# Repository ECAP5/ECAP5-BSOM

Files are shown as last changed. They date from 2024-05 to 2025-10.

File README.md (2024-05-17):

<br />
<div align="center">
    

  <h3 align="center">ECAP5-BSOM</h3>

  <p align="center">
    System-On-Module board for ECAP5
    <br />
    <a href="https://ecap5.github.io/ECAP5-BSOM/"><strong>Explore the docs »</strong></a>
    <br />
  </p>
</div>

## Licenses

- Software and configuration files are distributed under the GPL-3.0 license.
- Hardware is distributed under the CERN-OHL-S license.

See licence files for more information.

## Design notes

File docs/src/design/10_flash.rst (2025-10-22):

(F7) FLASH
==========

Functional description
----------------------

Design constraints
------------------

.. requirement:: D_FLASH_01
   :rationale: Only 32MBits are required to store the FPGA bitstream but the extra storage can be used by the user more easily than the eMMC. This reference supports optional programmable QSPI interface.

   The board shall include a 128Mbits NOR flash memory with reference W25Q128JVPIM to store the FPGA bitstream used in Quad-SPI configuration.

The following requirements are extracted from the datasheet of W25Q128JVPIM [:ref:^DS1 <reftable>^].

.. requirement:: D_FLASH_01
   :rationale: This corresponds to a 10% precision arround 3.3V.
   :derivedfrom: U_FLASH_01

   The VCC supply voltage shall be within 3.0V and 3.6V with a current capacity of 25mA.

.. requirement:: D_FLASH_02
   :derivedfrom: U_FLASH_01

   The CS input shall track the VCC supply levet at power-up and power-down using a pull-up resistor.

.. requirement:: D_FLASH_03
   :derivedfrom: U_FLASH_01

   The time between VCC reaching 3.0V to the CS pin being pulled low shall be at least 20us.

This requirement implies that the FPGA must not start its configuration before 20us after VCC reaches 3.0V.

.. requirement:: D_FLASH_04
   :derivedfrom: U_FLASH_01

   The time between VCC reaching 2.0V and the first write instruction shall be at least 5ms.

This requirement is only provided as information as write operations are only performed by the board designer while the board is already up and running.

Circuit diagram
---------------

Design calculations
-------------------

Simulation results
------------------

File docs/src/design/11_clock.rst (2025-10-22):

(F8) CLOCK
==========

Functional description
----------------------

Design constraints
------------------

.. requirement:: D_OSC_01
   :rationale: 40MHz LVCMOS, Enable/Disable on pin 1, 3.2x2.5mm package, 3.3VDC±5% supply, ±50ppm precision, -40 to +85°C temperature range.

   A 40 MHz reference oscillator shall be connected to one of the FPGA's global clock inputs, with reference XLH335040.000000I.

The following requirements are extracted from the datasheet of XLH736030.000000I [:ref:^DS6 <reftable>^].

Supply Voltage
^^^^^^^^^^^^^^

.. requirement:: D_OSC_01
   :derivedfrom: U_OSC_01

   The VDD supply voltage shall be within 3.135V and 3.465V with a current capacity of 35mA.

.. requirement:: D_OSC_02
   :derivedfrom: U_OSC_01

   A 0.01uF bypass capacitor shall be placed between VDD and GND.

Circuit diagram
---------------

Design calculations
-------------------

Simulation results
------------------

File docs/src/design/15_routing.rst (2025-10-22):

Routing
=======

Stackup
-------

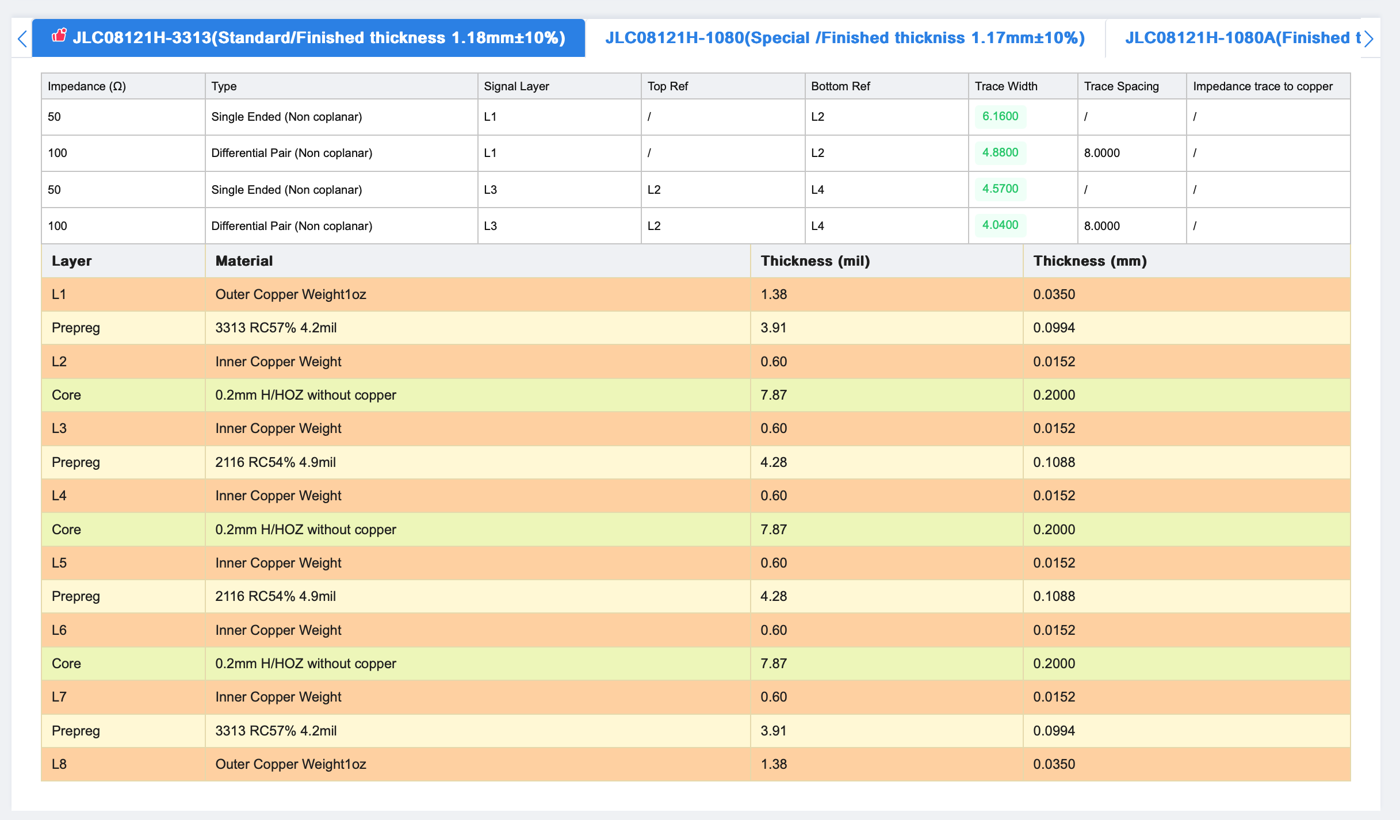
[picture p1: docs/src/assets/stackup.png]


The stackup used is JLCPCB's JLC08121H-3313 1.2mm pcb stackup.

.. flat-table:: Layer allocation
   :header-rows: 1
   :width: 100%

   * - Layer
     - Allocation

   * - Top layer L1
     - High-Speed signals

   * - Inner Layer L2
     - GND

   * - Inner Layer L3
     - High-Speed signals

   * - Inner Layer L4
     - Power

   * - Inner Layer L5
     - Power

   * - Bottom layer L6
     - High-Speed signals

   * - Bottom layer L7
     - GND

   * - Bottom layer L8
     - High-Speed signals

Trace impedance
---------------

.. flat-table:: Net classes
   :header-rows: 1
   :width: 100%

   * - Impedance
     - Layer
     - Trace width
     - Differencial-pair spacing

   * - Single-ended 50ohms
     - L1/L6
     - 6.16mil (0,156464mm)
     - N/A

   * - Differencial 100ohm
     - L1/L6
     - 4.88mil (0,123952mm)
     - 8.0mil (0,2032mm)

   * - Single-ended 50ohms
     - L4
     - 4.57mil (0,116mm)
     - N/A

   * - Differencial 100ohm
     - L4
     - 4.04mil (0,102616mm)
     - 8.0mil (0,2032mm)

Signal propagation
------------------

The propagation speed is computed with the following formulas :

.. math::

   v_{\text{microstrip}} = \frac{c_{\text{vacuum}}}{\sqrt{Dk_{eff}}}

.. math::

   v_{\text{stripline}} = \frac{c_{\text{vacuum}}}{\sqrt{Dk}}

where Dkeff for a 0.15mm stripline with a Dk of 4.6 is 2.87749 and the speed of light in vacuum is 299792458m/s.

.. flat-table:: Trace propagation on stackup layers
   :header-rows: 1
   :width: 100%
   
   * - Layer
     - Type
     - Propagation

   * - L1/L6
     - Single-Ended
     - ~5ps/mm

   * - L4
     - Single-Ended
     - ~7ps/mm

   * - L1/L6
     - Differencial
     - 

   * - L4
     - Differencial
     -

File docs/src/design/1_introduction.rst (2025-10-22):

Introduction
============

Purpose
-------

This documents aims at defining the functional requirements for ECAP5-BSOM as well as documenting the design process.

Product Scope
-------------

ECAP5-BSOM is a System-On-Module board which shall provide ECAP5 with a general-purpose FPGA platform including integrated memory, flash storage and high-speed interfaces.

Intended Use
-------------------------

ECAP5-BSOM is targetted at ECAP5 

Conventions
-----------

Requirement format
^^^^^^^^^^^^^^^^^^

This document details requirements with the following format :

.. list-table:: Sample requirement
  :width: 100%
  :widths: 10 90

  * - **ID**
    - Requirement_ID

  * - **Description**
    - Requirement description

  * - **Rationale**
    - Requirement rationale

  * - **DerivedFrom**
    - Other_Requirement_ID

with requirement IDs having the following format :

  * ``U_*``: User requirements
  * ``D_*``: Design requirements

Definitions and Abbreviations
-----------------------------

.. todo:: Update the ref table

.. _reftable:

References
----------

.. list-table::
  :header-rows: 1
  :widths: 10 20 15 55
  :width: 100%
  
  * - Reference
    - Date
    - Version
    - Title

  * - DS1
    - March 27, 2018
    - Revision F
    - W25Q128JV 3V 128M-Bit Serial Flash Memory with Dual/Quad SPI

  * - DS2
    - October 1, 2019
    - Revision 2.0
    - THGBMJG6C1LBAIL e-MMC Module

  * - DS3
    - July 20, 2022
    - Revision H2
    - IS61WV25616BLL 256K x 16 High Speed Asynchronous CMOS Static RAM 

  * - DS4
    - September 16, 2020
    - Revision C4
    - IS42S16160J 16Meg x16 256Mb Synchronous DRAM

  * - DS5
    - December 11, 2017
    - Revision B
    - IS43DR16320E 32Mx16 DDR2 DRAM

  * - DS6
    - September 21, 2023
    - N/A
    - Plastic Package Ultra Miniature Pure Silicon Clock Oscillators

  * - AN1
    - May, 2023
    - 1.4
    - FPGA-TN-02210 Power Consumption and Management for ECP5 and ECP5-5G Devices

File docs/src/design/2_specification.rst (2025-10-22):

Specification
=============

.. requirement:: U_FPGA_01
   :rationale: 85k LUTs with 365 I/Os. The speed grade of the part is not specified.

   The board shall include a Lattice ECP5 FPGA with reference LFE5U-85F-*BG756C.

.. requirement:: U_CLOCK_01

   The board shall include a 40MHz clock generator which shall be connected to one of the FPGA's global input clock pins.

.. requirement:: U_MEMORY_01

   The board shall include a 16-bit SRAM memory IC.

.. requirement:: U_MEMORY_02

   The board shall include two 16-bit SDRAM memory ICs to form a 32-bit data bus (shared address bus, separate data/ctrl buses).

.. requirement:: U_MEMORY_03

   The board shall include a 8-bit DDR2 memory IC.

.. note:: Multiple different memory technologies are integrated into the board to allow experimenting with memory controller development.

.. requirement:: U_STORAGE_01
   :rationale: 32Mb of storage is enough to store the FPGA bitstream but a bigger IC can be used to store user data.

   The board shall include a Quad-SPI Flash memory IC with at least 32Mb of storage which shall be connected to the FPGA sysConfig pins.

.. requirement:: U_STORAGE_02

   The board shall include an eMMC flash memory IC with HS200 support.

.. requirement:: U_CONNECTOR_01

   The board shall expose its various interfaces using a DDR4 SO-DIMM 260pin edge-card connector with the following pinout



.. list-table:: SO-DIMM IO Connector Signal Description
   :header-rows: 1
   :width: 100%

   * - Name
     - Type
     - Description

   * - JTAG_TCK
     - I
     - JTAG clock input
   * - JTAG_TDI
     - I
     - JTAG data input
   * - JTAG_TDO
     - O
     - JTAG data output
   * - JTAG_TMS
     - I
     - JTAG test mode select input
   * - SE[0-67]
     - I/O
     - Single-Ended general purpose 3v3 input/output
   * - RTD[0-64][P/N]
     - I
     - General purpose input/output LVDS2V5
   * - RESET_I
     - I
     - Reset input
   * - VIN9_20
     - 
     - Main power input 9~20V
   * - unused
     - 
     - 
   * - GND
     - 
     - 

.. note:: Unused pins are left unconnected but reserved on the connector for future use.

.. requirement:: U_POWER_01

   The board shall be powered by the 9-15V power inputs from the IO connector.

.. requirement:: U_MECHANICAL_01
   :rationale: The board can be as tall as needed.

   The board shall match the DDR4 SO-DIMM edge-card horizontal dimensions and features.

.. requirement:: U_MECHANICAL_02

   The board shall include mounting holes around the FPGA to mount a heatsink.

.. requirement:: U_LED_01

   The board shall include a status LED which shall indicicate the status of the FPGA.

.. requirement:: U_LED_02

   The board shall include a user LED which shall be driven by the FPGA.

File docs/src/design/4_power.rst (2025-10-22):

(F1) Power
==========

Functional description
----------------------

The power sub-circuit is in charge of converting the supply voltage from the IO connector to the following supply voltages required for the board's operation :

.. flat-table:: Supply Voltage Requirements
   :header-rows: 1
   :width: 100%

   * - Voltage
     - Current capacity requirement

   * - 1.1V ±5%
     - 3.5A
   * - 2.5V ±5%
     - 500mA
   * - 3.3V ±5%
     - 1A
   * - 1.8V ±5%
     - 500mA

The sub-circuit enables the voltage regulators in the following sequence, with a 10ms delay:



|

.. note:: The 3.3V voltage regulator is enabled by default so it can power the power sequencing IC.

The power sub-circuit also includes power monitoring ICs (IN219) to measure both voltage and current over an I2C bus. The following I2C addresses are used :

.. flat-table:: Supply monitoring I2C addresses
   :header-rows: 1
   :width: 100%

   * - Supply
     - I2C address

   * - 1.1V
     - 0x85
   * - 1.8V
     - 0x84
   * - 2.5V
     - 0x81
   * - 3.3V
     - 0x80

Power monitors are powered by a separate 5V LDO.

Design constraints
------------------

N/A

Circuit diagram
---------------

1.1V regulator
``````````````

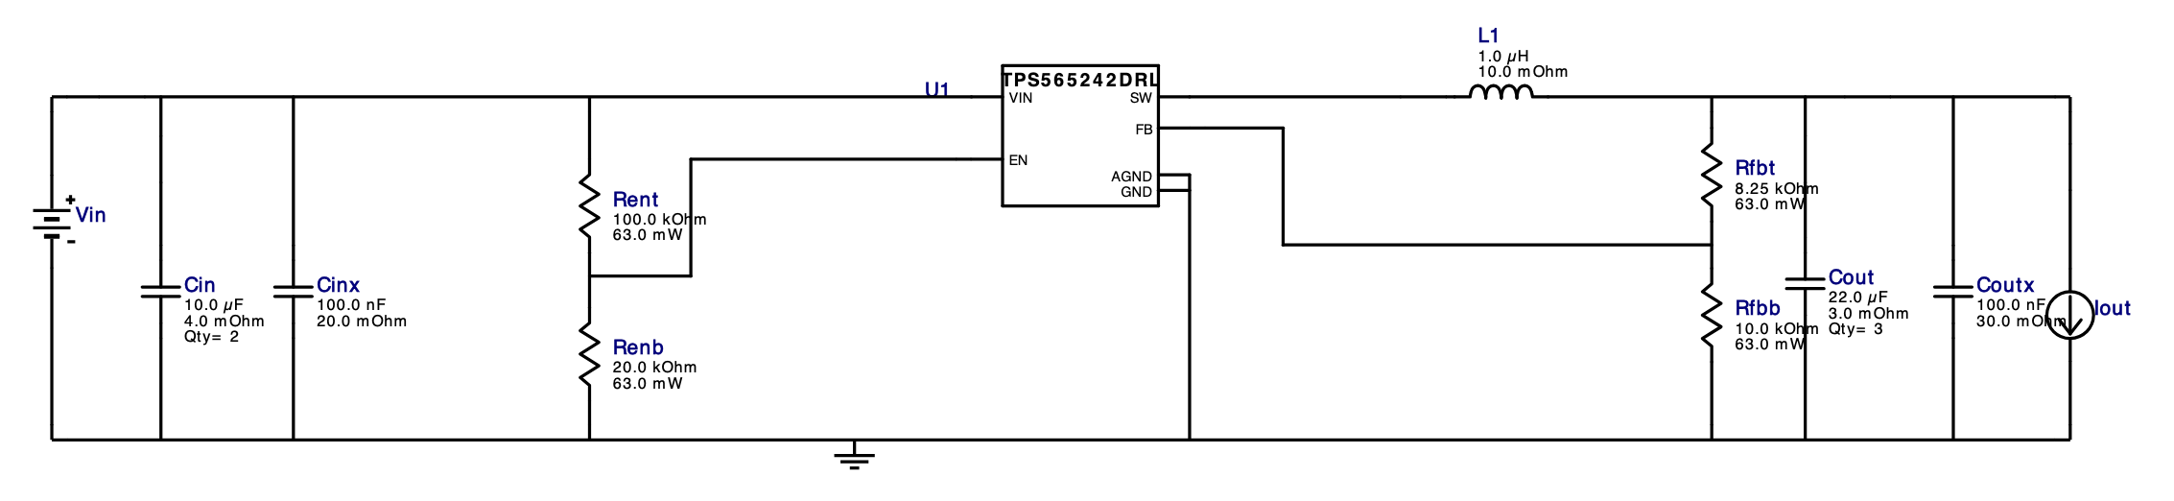
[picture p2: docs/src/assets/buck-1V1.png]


Refer to the following document for full details : `buck-1.1-report.pdf <../_static/buck-1.1-report.pdf>`_.

1.8V regulator
``````````````

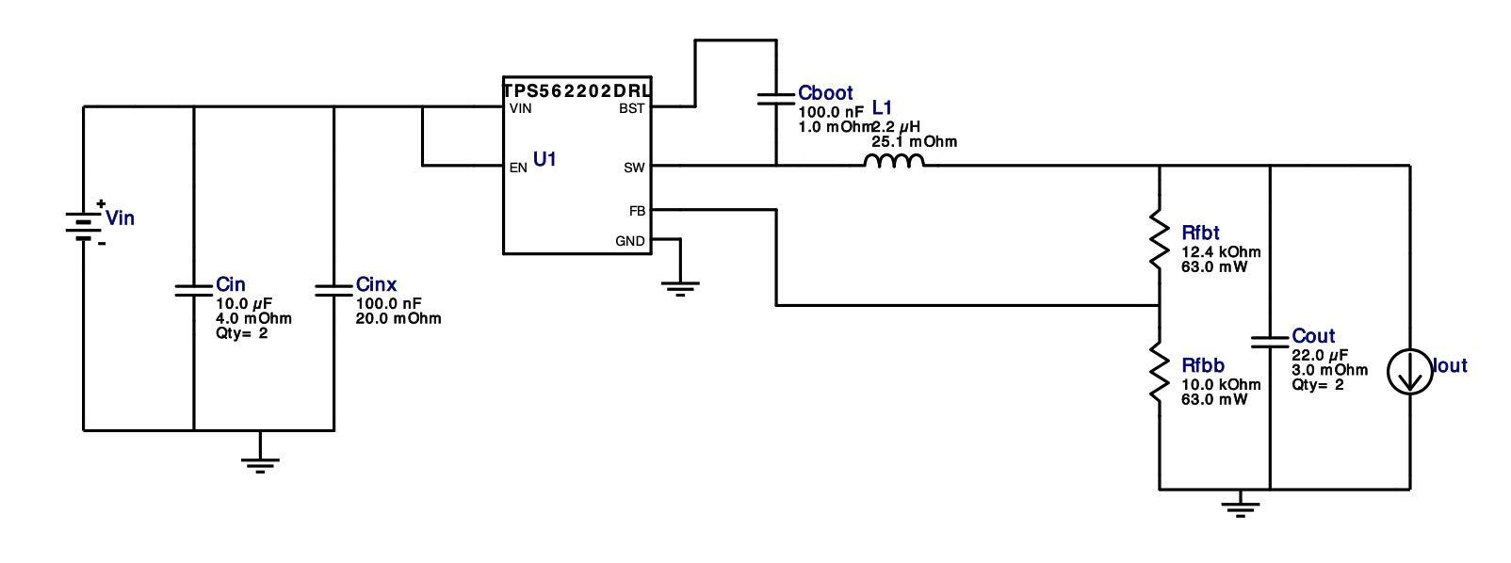
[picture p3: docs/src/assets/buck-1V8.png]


Refer to the following document for full details : `buck-1.8-report.pdf <../_static/buck-1.8-report.pdf>`_.

2.5V regulator
``````````````

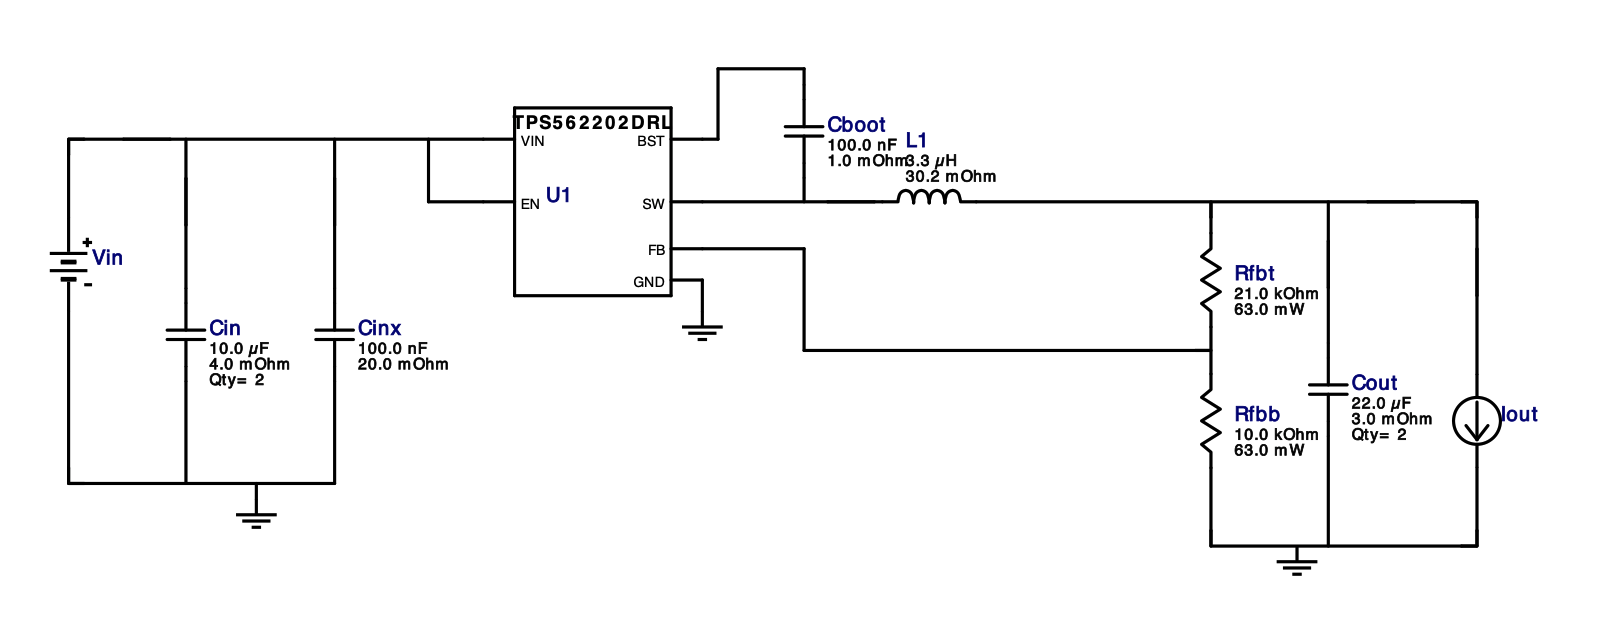
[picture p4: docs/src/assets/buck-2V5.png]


Refer to the following document for full details : `buck-2.5-report.pdf <../_static/buck-2.5-report.pdf>`_.

3.3V regulator
``````````````

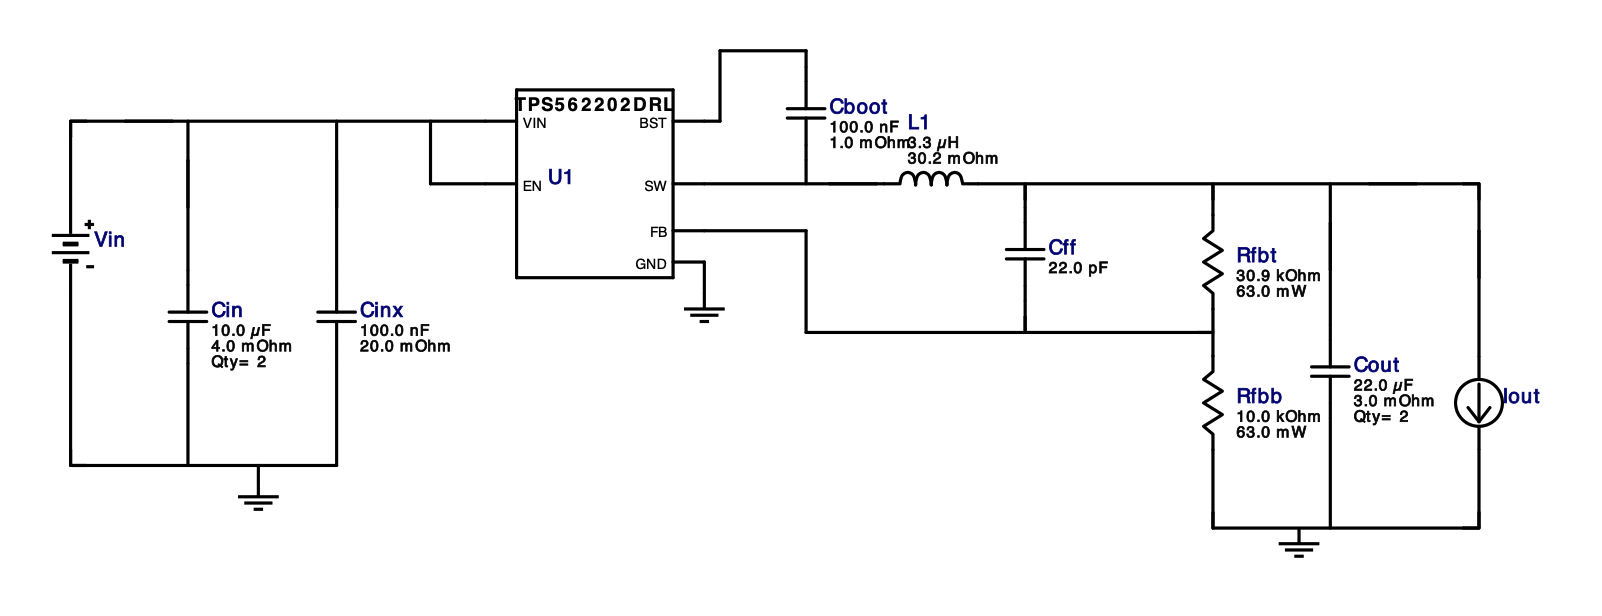
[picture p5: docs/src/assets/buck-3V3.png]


Refer to the following document for full details : `buck-3.3-report.pdf <../_static/buck-3.3-report.pdf>`_.

Power sequencing
````````````````



.. flat-table:: Power sequencer IC
   :stub-columns: 1
   :width: 100%

   * - IC
     - LM3880
   * - Sequence Number
     - 1 (1-2-3 / 3-2-1)
   * - Timing Designator
     - AA (10ms)
   * - Ordering reference
     - LM3880MF*-1AA

Design calculations
-------------------

Supply requirements
```````````````````

In order to perform a rough FPGA power estimation, the following assumptions were taken :

- LFE5U-85F-8BG756C reference
- 200MHz internal frequency
- 25% Activity Factor (as stated in :ref:`AN1 <reftable>`)
- 70% logic utilization
- 100% BRAM utilization
- 64 LVDS input differential pairs
- eMMC IOs
- SRAM Address/Data IOs
- SDRAM Address/DQ IOs
- DDR2 Address/DQ IOs

.. note:: I/O utilization isn't precisely modelled as the IO power consumption is low. Margins will be taken to prevent any supply issues.

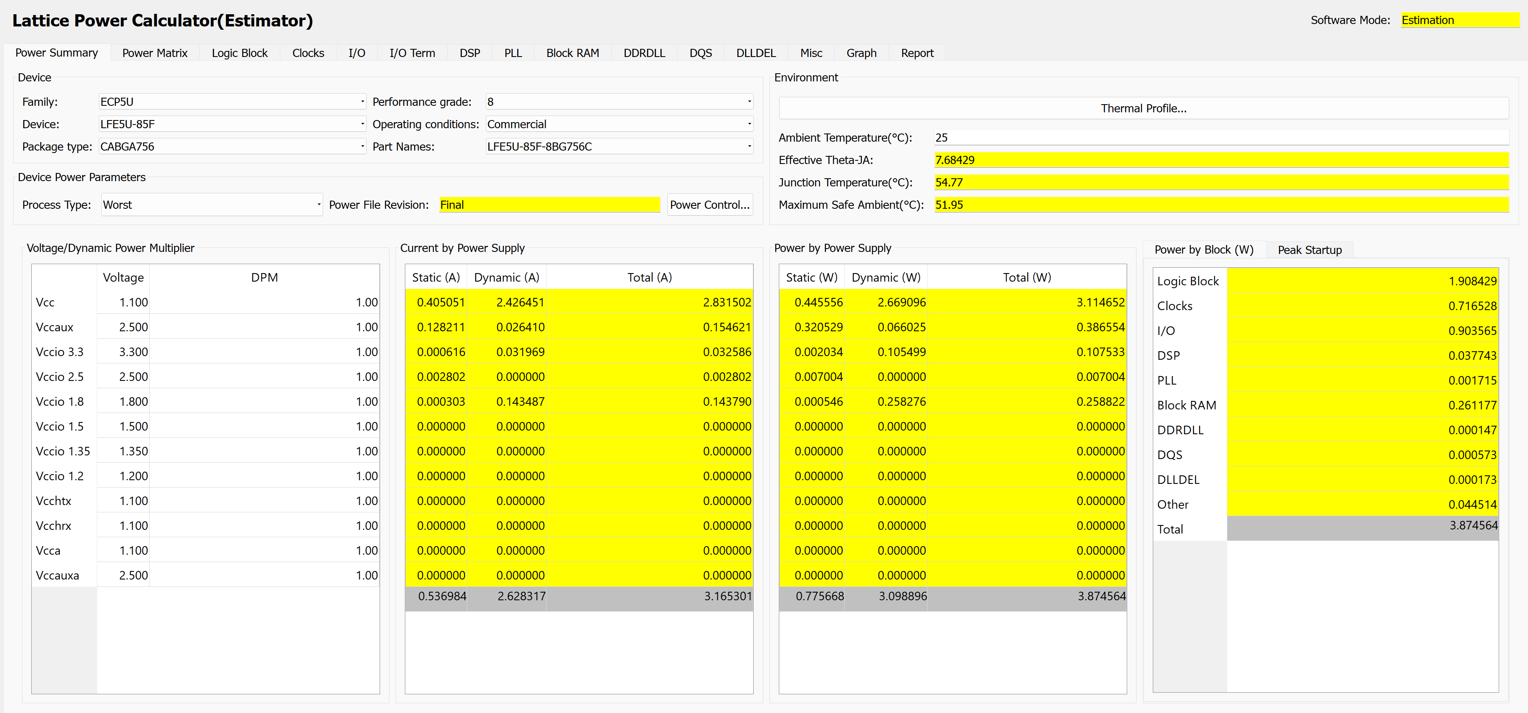
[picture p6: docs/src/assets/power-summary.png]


|

The following table outlines the voltage requirements of the specified components :

.. flat-table:: Component Supply Voltage Requirements
   :header-rows: 1
   :width: 100%

   * - Component
     - Name
     - Voltage
     - Max Current
     - Description
   
   * - :rspan:`3` LFE5U-85F-*BG756C
     - VCC
     - 1.1V ±5%
     - 3A
     - Core Supply Voltage
   * - VCCAUX
     - 2.5V ±5%
     - 200mA
     - Auxilary Supply Voltage
   * - VCCIO[*]
     - 
     - 
     - 
   * - VCCIO8
     - 3.3V ±10%
     - 100mA
     - sysIO bank Supply Voltage
   * - IS61W25616BLL
     - VDD
     - 3.3V ±5%
     - 50mA
     - Supply Voltage
   * - :rspan:`1` IS42S16160J x2
     - VDD
     - 3.3V ±10%
     - 140mA x2
     - Supply Voltage
   * - VDDQ
     - 3.3V ±10%
     - *included in VDD*
     - I/O Supply Voltage
   * - :rspan:`2` IS43DR86400E
     - VDD
     - 1.8V ±5%
     - 185mA
     - Supply Voltage
   * - VDDQ
     - 1.8V ±5%
     - *included in VDD*
     - I/O Supply Voltage
   * - VDDL
     - 1.8V ±5%
     - *included in VDD*
     - DLL Supply Voltage
   * - W25Q158JVPIM
     - VCC
     - 3.3V ±10%
     - 25mA
     - Supply Voltage
   * - :rspan:`1` ASFC4G31M-51BIN
     - VCCQ
     - 1.8V ±8%
     - 120mA
     - Host Interface Supply Voltage
   * - VCC
     - 3.3V ±10%
     - 120mA
     - Memory Supply Voltage

Power Sequencing
````````````````

.. flat-table:: Power-up timings
   :header-rows: 1
   :stub-columns: 2
   :width: 100%

   * - IC
     - Voltage
     - Max ramp rate
     - Max start time
   * - ST1S41PHR
     - 1.1V
     - 1.1mV/us
     - 1ms
   * - L6981NDR
     - 1.8V
     - 1.8mV/us
     - 1.6ms
   * - L6981NDR
     - 2.5V
     - 2.5mV/us
     - 1.6ms
   * - L6981NDR
     - 3.3V
     - 3.3mV/us
     - 1.6ms

The following formula is used to compute the value of :math:`C_{\text{en}}` which applies a delay to the start of the sequence:

.. math::

   t_{\text{enable_delay}} = \frac{1.25V * C_{\text{en}}}{7 \mu A}

:math:`t_{\text{enable_delay}}` must greater than the start time of the 3.3V regulation (ie. 1.6ms), therefore :

.. math::

  C_{\text{en}} = 56nF \implies t_{\text{enable_delay}} = 10ms

Power monitoring
````````````````

In order to minimize the voltage drop induced by the shunt resistor, the following values have been chosen, considering a full range shunt resistor voltage of 40mV :

.. flat-table:: Power monitoring shunt resistor
   :header-rows: 1
   :width: 100%

   * - Supply
     - Max current
     - Shunt resistor
     - Max voltage drop

   * - 1.1V
     - 4A
     - 2.2mOhms
     - 8.8mV
   * - 1.8V
     - 1A
     - 22mOhms
     - 22mV
   * - 2.5V
     - 1A
     - 39mOhms
     - 39mV
   * - 3.3V
     - 1A
     - 39mOhms
     - 39mV

.. note:: The smaller shunt resistors on 1.1V and 1.8V supplies will result in a lower power measurement precision but allows for a greater voltage margin.

Simulation results
------------------

1.1V Core
`````````

Refer to the following document for full details : `buck-1.1-report.pdf <../_static/buck-1.1-report.pdf>`_.

1.8V
````

Refer to the following document for full details : `buck-1.8-report.pdf <../_static/buck-1.8-report.pdf>`_.

2.5V
````

Refer to the following document for full details : `buck-2.5-report.pdf <../_static/buck-2.5-report.pdf>`_.

3.3V
````

Refer to the following document for full details : `buck-3.3-report.pdf <../_static/buck-3.3-report.pdf>`_.

Power sequencing
````````````````

N/A

Power integrity
---------------

A power integrity simulation was performed on the 1.1V rail as it is the most constrained. The voltage drop observed at 4A was 10mV which is within the range of the requirements.

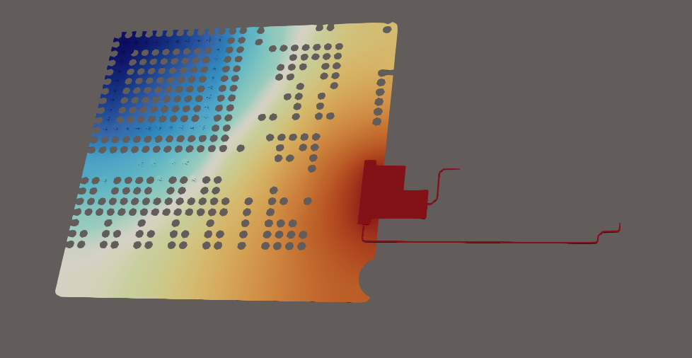
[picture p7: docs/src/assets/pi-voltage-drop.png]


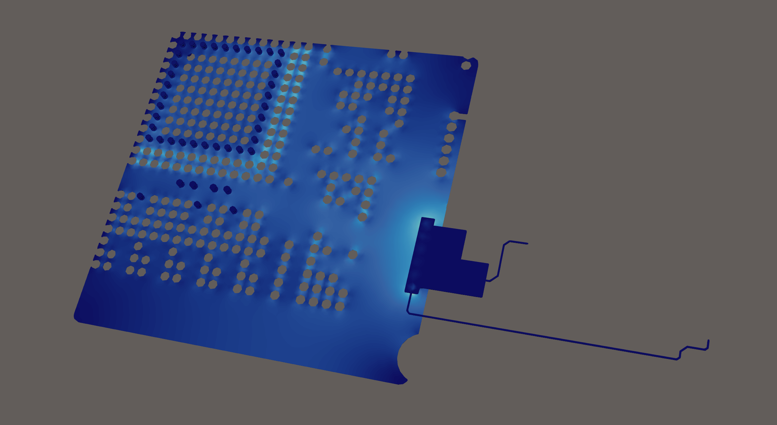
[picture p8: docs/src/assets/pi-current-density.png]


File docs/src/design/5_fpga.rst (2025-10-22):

(F2) FPGA
=========

Design constraints
------------------

Operating Conditions
^^^^^^^^^^^^^^^^^^^^

.. requirement:: D_FPGA_01
   :derivedfrom: U_FPGA_01

   A power estimation for the FPGA supply voltages shall be performed.

.. requirement:: D_FPGA_02
   :rationale: This corresponds to a 5% precision around 1.1V.
   :derivedfrom: U_FPGA_01

   The VCC supply voltage shall be within 1.045V and 1.155V.

.. requirement:: D_FPGA_03
   :rationale: This corresponds to a 5% precision around 2.5V.
   :derivedfrom: U_FPGA_01

   The VCCAUX supply voltage shall be within 2.375V and 2.625V.

.. requirement:: D_FPGA_04
   :derivedfrom: U_FPGA_01

   The VCCAUX supply voltage ramp shall not exceed 30mV/us during power-up.

.. requirement:: D_FPGA_05
   :derivedfrom: U_FPGA_01

   VCCIO[0:8] supply voltages shall be between 1.14V and 3.465V.

.. note:: Specific VCCIO[0:8] supply voltages are defined in the design section based on the FPGA pinout.

.. requirement:: D_FPGA_10
   :derivedfrom: U_FPGA_01

   Power supply ramp rate for all supplies shall not exceed 10V/ms.

.. requirement:: D_FPGA_11
   :derivedfrom: U_FPGA_01

   The following power-up sequence of supply voltages shall be implemented : VCCIO*, VCCAUX, VCC.

.. note:: The current requirement for the FPGA supply voltages is not defined in the FPGA datasheet. A power estimation is performed in the design section to provide upper current bounds.

.. requirement:: D_FPGA_12
   :derivedfrom: U_FPGA_01

   The FPGA junction temperature shall not exceed 85°C.

Configuration
^^^^^^^^^^^^^

As the FPGA sysCONFIG configuration is MSPI, only requirements targetting this configuration method are outlined.

.. requirement:: D_FPGA_13
   :derivedfrom: U_FPGA_01

   4.7kohms pull-up resistors shall be placed between the following signals and VCCIO8: TDI, TMS, TDO.

.. requirement:: D_FPGA_14
   :derivedfrom: U_FPGA_01

   A 4.7kohms pull-down resistor shall be placed between TCK and GND.

.. requirement:: D_FPGA_15
   :derivedfrom: U_FPGA_01

   4.7kohms pull-up resistors shall be placed between the following signals and VCCIO8: PROGRAMN and INITN.

.. requirement:: D_FPGA_16
   :derivedfrom: U_FPGA_01

   A 10kohms pull-up resistor shall be placed between CSSPIN and VCCIO8.

.. requirement:: D_FPGA_17
   :derivedfrom: U_FPGA_01

   A 1kohms pull-up resistor shall be placed between MCLK and VCCIO8.

.. requirement:: D_FPGA_18
   :derivedfrom: U_FPGA_01

   10kohms pull-up resistors shall be placed between CFG[2:0] and VCCIO8 when the configuration bit shall be 1. CFG[2:0] shall be directly connected to GND otherwise.

Configuration
-------------

CFGMDN[2:0]
^^^^^^^^^^^

.. requirement:: D_CONF_01
   :rationale: The sysCONFIG pins are configured as Master SPI.

   The CFGMDN[2:0] pins shall be configured as 010 using 4.7k pull-up or pull-down resistors.

IO[3:0]
^^^^^^^

.. requirement:: D_CONF_02

   10k pull-up resistors shall be used on sysCONFIG IO[3:0] pins.
   
.. requirement:: D_CONF_03

   A 1k pull-up resistor shall be used on sysCONFIG CLK pin.

PROGRAMN
^^^^^^^^

.. requirement:: D_CONF_04

   A 100nF capacitor shall be placed between PROGRAMN and GND.

INITN and DONE
^^^^^^^^^^^^^^

INITN is open-drain.

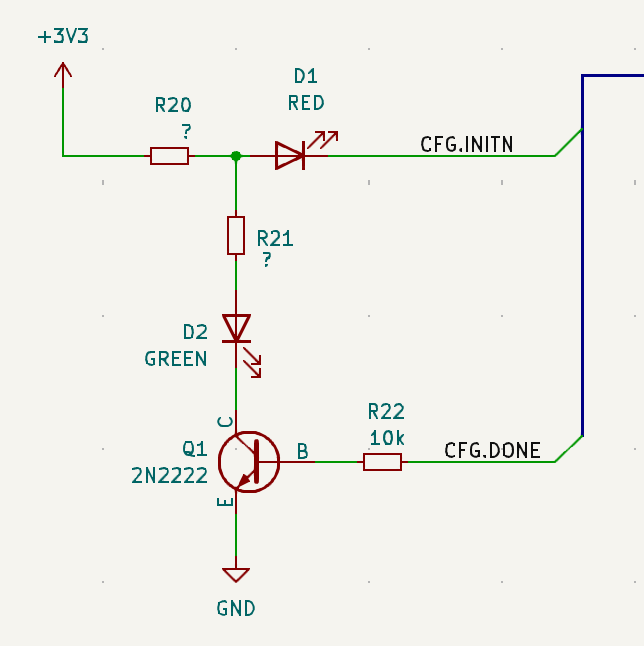
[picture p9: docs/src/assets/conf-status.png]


FPGA Pinout
-----------

The following table outlines the FPGA interface signals and their pinout constraints.

.. note:: The I/O column is from the FPGA's perspective to ease the creation of design constraints files.

.. csv-table:: Oscillator interface signals
   :header-rows: 1
   :width: 100%
   :file: ../assets/osc-pinout.csv
   :delim: ;

.. csv-table:: Flash interface signals
   :header-rows: 1
   :width: 100%
   :file: ../assets/flash-pinout.csv
   :delim: ;

.. csv-table:: eMMC interface signals
   :header-rows: 1
   :width: 100%
   :file: ../assets/emmc-pinout.csv
   :delim: ;

.. csv-table:: SRAM interface signals
   :header-rows: 1
   :width: 100%
   :file: ../assets/sram-pinout.csv
   :delim: ;

.. csv-table:: SDRAM interface signals
   :header-rows: 1
   :width: 100%
   :file: ../assets/sdram-pinout.csv
   :delim: ;

.. csv-table:: DDR2 interface signals
   :header-rows: 1
   :width: 100%
   :file: ../assets/ddr2-pinout.csv
   :delim: ;

.. csv-table:: IO connector interface signals
   :header-rows: 1
   :width: 100%
   :file: ../assets/io-pinout.csv
   :delim: ;

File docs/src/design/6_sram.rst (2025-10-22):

(F3) SRAM
=========

Functional description
----------------------

The SRAM sub-circuit is in charge of providing the user with 4MiB of Asynchronous SRAM.

Design constraints
------------------

.. requirement:: D_MEMORY_01

   The board shall include a 256k x 16bits Asynchronous SRAM with reference IS61WV25616BLL up to -8 speed grade.

The following requirements are extracted from the datasheet of IS61WV25616BLL [:ref:^DS3 <reftable>^].

.. requirement:: D_SRAM_01
   :rationale: This corresponds to an 5% precision arround 3.3V.
   :derivedfrom: U_MEMORY_01

   The VDD supply voltage shall be within 3.135V and 3.465V with a current capacity of 50mA.

.. requirement:: D_SRAM_02
   :derivedfrom: U_MEMORY_01

   The following pins shall not exceed VDD+0.3V : Address, Data and Control pins.

.. requirement:: D_SRAM_03
   :derivedfrom: U_MEMORY_01

   The following pins shall not be lower than -0.3V : Address, Data and Control pins.

Circuit diagram
---------------

Design calculations
-------------------

Simulation results
------------------

Pre-layout
``````````

The goal of the pre-layout simulation is to adjust the high-speed bus termination.

Transient behavior
^^^^^^^^^^^^^^^^^^

.. note:: No signal-integrity simulations are performed for revision 1.0.0

Eye Diagram
^^^^^^^^^^^

.. note:: No signal-integrity simulations are performed for revision 1.0.0

Post-layout
```````````

The goal of the post-layout simulation is to simulate the high-speed bus taking into account the routed trace geometry.

Transient behavior
^^^^^^^^^^^^^^^^^^

.. note:: No signal-integrity simulations are performed for revision 1.0.0

Eye Diagram
^^^^^^^^^^^

.. note:: No signal-integrity simulations are performed for revision 1.0.0

Crosstalk
^^^^^^^^^

.. note:: No signal-integrity simulations are performed for revision 1.0.0

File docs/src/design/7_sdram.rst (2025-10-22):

(F4) SDRAM
==========

Functional description
----------------------

Design constraints
------------------

.. requirement:: D_MEMORY_02

   The board shall include two 16M x 16bits 256Mb Synchronous DRAM with reference IS42S16160J up to -6 speed grade.

The following requirements are extracted from the datasheet of IS42S16160J [:ref:^DS4 <reftable>^].

.. requirement:: D_SDRAM_01
   :rationale: This corresponds to an 10% precision arround 3.3V.
   :derivedfrom: U_MEMORY_02

   The VDD and VCCQ supply voltage shall be within 3.0V and 3.6V with a current capacity of 140mA x2.

.. requirement:: D_SDRAM_02
   :derivedfrom: U_MEMORY_02

   The following pins shall not exceed VDD+0.3V : Address, Data and Control pins.

.. requirement:: D_SDRAM_03
   :derivedfrom: U_MEMORY_02

   The following pins shall not be lower than -0.3V : Address, Data and Control pins.

Circuit diagram
---------------

Design calculations
-------------------

Simulation results
------------------

Pre-layout
``````````

The goal of the pre-layout simulation is to adjust the high-speed bus termination.

The address and command trace stubs associated to the fly-by routing topology shall be smaller than 0.3/0.1Gbps = 3inch so no terminating resistors are needed.

Transient behavior
^^^^^^^^^^^^^^^^^^

.. note:: No signal-integrity simulations are performed for revision 1.0.0

Eye Diagram
^^^^^^^^^^^

.. note:: No signal-integrity simulations are performed for revision 1.0.0

Post-layout
```````````

The goal of the post-layout simulation is to simulate the high-speed bus taking into account the routed trace geometry.

Transient behavior
^^^^^^^^^^^^^^^^^^

.. note:: No signal-integrity simulations are performed for revision 1.0.0

Eye Diagram
^^^^^^^^^^^

.. note:: No signal-integrity simulations are performed for revision 1.0.0

Crosstalk
^^^^^^^^^

.. note:: No signal-integrity simulations are performed for revision 1.0.0

Routing
-------

Length matching
```````````````

According to AN42S01 "ISSI SRAM/SDRAM Layout Guide", the longest-to-shortest trace length difference shall be matched to <20.32mm (800mils).

For SDRAM1, the signals are all point-to-point with a maximum trace length difference of (16.93mm-5.3836) = 11.5464mm.

For SDRAM0, some signals are point-to-point whereas the address bus is shared with SDRAM1 and is therefore much longer.

.. flat-table:: Address bus trace length to SDRAM0
   :header-rows: 1
   :width: 100%

   * - Signal
     - Traces
     - Length

   * - A0 
     - 12.0144 + 10.4529
     - 22.4673mm

   * - A1 
     - 12.3720 + 11.0783 
     - 23.4503mm

   * - A2 
     - 12.7545 + 10.3013 
     - 23.0558mm

   * - A3
     - 12.5851 + 10.2281 
     - 22.8132mm

   * - A4 
     - 12.1668 + 10.2658 
     - 22.4326mm

   * - A5 
     - 10.9060 + 13.4390 
     - 24.345mm

   * - A6 
     - 10.6935 + 14.3101 
     - 25.0036mm

   * - A7 
     - 11.2030 + 13.5777 
     - 24.7807mm

   * - A8 
     - 10.9296 + 16.0072 
     - 26.9368mm

   * - A9 
     - 10.7349 + 11.3978 
     - 22.1327mm

   * - A10 
     - 12.3981 + 9.6156 
     - 22.0137mm

   * - A11 
     - 10.6521 + 13.3707 
     - 24.0228mm

   * - A12
     - 11.2846 + 14.6813 
     - 25.9659mm

   * - BA0
     - 13.8279 + 12.6978 
     - 26.5257mm

   * - BA1
     - 12.7992 + 8.8939 
     - 21.6931mm

The signals shall be longer than 7mm.

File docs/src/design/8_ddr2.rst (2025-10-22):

(F5) DDR2
=========

Functional description
----------------------

Design constraints
------------------

.. requirement:: D_MEMORY_03
   :rationale: The -5B speed grade corresponds to DDR2-400B standard.

   The board shall include a 64M x 8bits 512Mb DDR2 Synchronous DRAM with reference IS43DR86400E up to -5B speed grade.

The following requirements are extracted from the datasheet of IS43DR86400E [:ref:^DS5 <reftable>^].

.. requirement:: D_DDR2_01
   :rationale: This corresponds to an 5% precision arround 1.8V.
   :derivedfrom: U_MEMORY_02

   The VDD, VDDL and VDDQ supply voltages shall be within 1.7V and 1.9V with a current capacity of .

.. requirement:: D_DDR2_02
   :derivedfrom: U_MEMORY_02

   The VDD voltage ramp time shall not be greater than 200ms from when VDD ramps from 300mV to VDD min.

.. requirement:: D_DDR2_03
   :derivedfrom: U_MEMORY_02

   During the VDD voltage ramp, VDD and VDDQ shall not be futher apart than 300mV.

.. requirement:: D_DDR2_04
   :rationale: This corresponds to an 2% precision arround 0.5*VDDQ.
   :derivedfrom: U_MEMORY_02

   The VREF voltage shall be within 0.882V and 0.918V.

.. requirement:: D_DDR2_05
   :derivedfrom: U_MEMORY_02

   Peak to peak AC noise on VREF shall not exceed ±2% of VREF(dc).

.. requirement:: D_DDR2_06
   :rationale: VTT of the transmitting device must track VREF of the receiving device.
   :derivedfrom: U_MEMORY_02

   The VTT voltage shall be within VREF - 0.04 and VREF + 0.04.

.. requirement:: D_DDR2_07
   :derivedfrom: U_MEMORY_02

   The peak amplitude for the overshoot and undershoot area of the following pins shall be lower than 0.5V : Address, Control, Clock, Data, Strobe and Mask.

.. requirement:: D_DDR2_08
   :derivedfrom: U_MEMORY_02

   The amplitude area above VDD and below VSS of the following pins shall be lower than 1.33 V-ns : Address and Control.

.. requirement:: D_DDR2_09
   :derivedfrom: U_MEMORY_02

   The amplitude area above VDD and below VSS of the following pins shall be lower than 0.38 V-ns : Clock, Data, Strobe and Mask.

Circuit diagram
---------------

Design calculations
-------------------

Simulation results
------------------

Pre-layout
``````````

The goal of the pre-layout simulation is to adjust the high-speed bus termination.

Transient behavior
^^^^^^^^^^^^^^^^^^

.. note:: No signal-integrity simulations are performed for revision 1.0.0

Eye Diagram
^^^^^^^^^^^

.. note:: No signal-integrity simulations are performed for revision 1.0.0

Post-layout
```````````

The goal of the post-layout simulation is to simulate the high-speed bus taking into account the routed trace geometry.

Transient behavior
^^^^^^^^^^^^^^^^^^

.. note:: No signal-integrity simulations are performed for revision 1.0.0

Eye Diagram
^^^^^^^^^^^

.. note:: No signal-integrity simulations are performed for revision 1.0.0

Crosstalk
^^^^^^^^^

.. note:: No signal-integrity simulations are performed for revision 1.0.0

Routing
-------

Length matching
```````````````

.. flat-table:: Signal trace length delay constraints
   :header-rows: 1
   :width: 100%

   * - Constraint
     - Description

   * - LC1
     - All data, address and command signals must be followed within +- 50ps

   * - LC2
     - Intra-pair mismatch +- 2ps

   * - LC3
     - Inter-pair mismatch +- 5ps

   * - LC4
     - Intra-byte-group mismatch +- 10ps

CLK and DQS intra-pair and inter-pair mismatches are ignored as they are exactly length matched.

CLK, DQS, Data and DM signals are routed on the same layer (L6) and are length matched to 0.03mm (2.1ps<10ps).

Signals on L3/L6 shall be matched to 23.9150mm +- 5mm (35ps<50ps))

Signals on L8 shall be matched to 23.9150mm +- 7mm (35ps<50ps))

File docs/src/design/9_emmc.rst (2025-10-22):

(F6) EMMC
=========

Functional description
----------------------

Design constraints
------------------

.. requirement:: D_FLASH_02

   The board shall include a 4GB eMMC flash memory with reference ASFC4G31M-51 with High Speed DDR and HS200 support.

The following requirements are extracted from the datasheet of ASFC4G31M-51 [:ref:^DS2 <reftable>^].

Supply Voltages
^^^^^^^^^^^^^^^

.. requirement:: D_EMMC_01
   :rationale: This corresponds to an 8% precision arround 1.8V.
   :derivedfrom: U_FLASH_02

   The VCCQ supply voltage shall be within 1.70V and 1.95V with a current capacity of 120mA.

.. requirement:: D_EMMC_02
   :rationale: This corresponds to an 10% precision arround 3.3V.
   :derivedfrom: U_FLASH_02

   The VCC supply voltage shall be within 2.70V and 3.60V with a current capacity of 120mA.

.. requirement:: D_EMMC_03
   :derivedfrom: U_FLASH_02

   Both a 4.7uF and a 100nF capacitors shall be placed between VDDI and VSS.

.. requirement:: D_EMMC_04
   :derivedfrom: U_FLASH_02

   Both a 10uF and a 100nF capacitors shall be placed between VCC and VSS.

.. requirement:: D_EMMC_05
   :derivedfrom: U_FLASH_02

   Both a 4.7uF and a 100nF capacitors shall be placed between VCCQ and VSS.

.. requirement:: D_EMMC_6
   :derivedfrom: U_FLASH_02

   The following signals shall be routed with transmission lines matched to 50ohms : DAT0-DAT7, CMD and CLK.

.. requirement:: D_EMMC_7
   :derivedfrom: U_FLASH_02

   The following signals shall be length matched up to ±1mm : DAT0-DAT7, CMD and CLK.

Circuit diagram
---------------

Design calculations
-------------------

Simulation results
------------------

Pre-layout
``````````

The goal of the pre-layout simulation is to adjust the high-speed bus termination.

Transient behavior
^^^^^^^^^^^^^^^^^^

.. note:: No signal-integrity simulations are performed for revision 1.0.0

Eye Diagram
^^^^^^^^^^^

.. note:: No signal-integrity simulations are performed for revision 1.0.0

Post-layout
```````````

The goal of the post-layout simulation is to simulate the high-speed bus taking into account the routed trace geometry.

Transient behavior
^^^^^^^^^^^^^^^^^^

.. note:: No signal-integrity simulations are performed for revision 1.0.0

Eye Diagram
^^^^^^^^^^^

.. note:: No signal-integrity simulations are performed for revision 1.0.0

Crosstalk
^^^^^^^^^

.. note:: No signal-integrity simulations are performed for revision 1.0.0

Routing
-------

Length matching
```````````````

.. flat-table:: Signal trace length delay constraints
   :header-rows: 1
   :width: 100%

   * - Constraint
     - Description

   * - LC1
     - Mismatch within DAT0~DAT7+DS <= 41ps

   * - LC2
     - CLK to DAT0~7+DS mismatch <= 41ps

   * - LC3
     - CLK to CMD mismatch <= 41ps

   * - LC4
     - CLK to RST_N mismatch <= 166ps

.. note:: Signals applicable to LC1 will be matched to the longest one of them

CLK and DAT0~DAT7+DS+CMD will be matched to 18.3917mm +- 3mm (21ps) on L3/L6 and 18.3917mm +- 5mm (25ps) on L8.

CLK and RST_N signals will be matched to 18.3917mm +- 14mm (100ps).

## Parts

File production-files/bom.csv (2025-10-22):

Manufacturer | MPN | Reference | Qty | Mouting Technology | Description | Footprint | Value
Murata Electronics | GRM21BR61A226ME44L | C1,C2,C12,C16 | 4 | SMD | 22u X5R 0805 10VDC | Capacitor_SMD:C_0805_2012Metric | 22u
Murata Electronics | GRM21BR61E106MA73L | C3,C6,C9,C13 | 4 | SMD | 10u X5R 0805 25VDC | Capacitor_SMD:C_0805_2012Metric | 10u
TDK | C1005X7R1C104M050BC | C4,C11,C15,C22,C87,C91,C93,C151,C153,C154,C155,C156 | 12 | SMD | 100n X7R 0402 | Capacitor_SMD:C_0402_1005Metric | 100n
Walsin | SH21B104K101CT | C5,C7,C8,C10,C14,C17,C18,C19 | 8 | SMD | 100n 0805 16VDC | Capacitor_SMD:C_0805_2012Metric | 100n
Murata Electronics | GCM155R71C563KA55D | C23 | 1 | SMD | 56n 0402 | Capacitor_SMD:C_0402_1005Metric | 56n
Murata Electronics | GRM033R60J474KE90J | C24,C25,C26,C27,C28,C29,C30,C31,C32,C37,C52,C53,C58,C59,C64,C65,C70,C71,C76,C77,C78,C79,C82,C83,C84,C86,C90,C129,C135 | 29 | SMD | 470n 0201 X5R | Capacitor_SMD:C_0201_0603Metric | 470n
TDK | C1608X7R1A106M080AT | C33,C34,C35,C124 | 4 | SMD | 10u 0603 X7R | Capacitor_SMD:C_0603_1608Metric | 10u
Murata Electronics | GRM033R60J104ME19J | C36,C39,C40,C41,C42,C43,C44,C45,C46,C47,C50,C51,C56,C57,C62,C63,C68,C69,C74,C75,C80,C81,C85,C96,C101,C102,C103,C104,C105,C106,C107,C108,C111,C112,C113,C114,C115,C119,C122,C123,C126,C128,C130,C131,C132,C133,C134,C142 | 48 | SMD | 100n 0201 X5R | Capacitor_SMD:C_0201_0603Metric | 100n
Murata Electronics | GRM155R6YA105ME11J | C38,C121,C136,C137,C138,C157,C158 | 7 | SMD | 1u 0402 X5R | Capacitor_SMD:C_0402_1005Metric | 1u
Murata Electronics | GRM033R60J103KA01D | C48,C49,C54,C55,C60,C61,C66,C67,C72,C73,C92,C94,C95,C98,C120,C143,C144,C145,C150,C152 | 20 | SMD | 10n 0201 X5R | Capacitor_SMD:C_0201_0603Metric | 10n
Murata Electronics | GRM155R60J103KA01D | C88 | 1 | SMD | 10n 0402 X5R | Capacitor_SMD:C_0402_1005Metric | 10n
Murata Electronics | GRM155R61H474ME11D | C89,C97,C99,C100,C109,C110,C116,C117,C118,C139,C140,C141 | 12 | SMD | 470n 0402 X5R | Capacitor_SMD:C_0402_1005Metric | 470n
Samsung Electro-Mechanics | CL10A475KP8NNNC | C125,C127,C146,C147,C148,C149 | 6 | SMD | 4.7u 0603 X5R | Capacitor_SMD:C_0603_1608Metric | 4.7u
Wurth Elektronik | 150060GS75000 | D1,D3,D4,D5 | 4 | SMD |  | LED_SMD:LED_0603_1608Metric | Green
Wurth Elektronik | 150060RS75000 | D2 | 1 | SMD |  | LED_SMD:LED_0603_1608Metric | Red
Bourns | XAL4020-102 | L1 | 1 | SMD |  | ECAP5-DPROC:Coilcraft_XAL4020 | 1u
Bourns | XAL4020-222 | L2 | 1 | SMD |  | ECAP5-DPROC:Coilcraft_XAL4020 | 2.2u
Bourns | XAL4030-332 | L3,L4 | 2 | SMD |  | ECAP5-DPROC:Coilcraft_XAL4030 | 3.3u
Vishay | CRCW040210K0FKEDC | R1,R2,R3,R4,R7,R8,R15,R16,R17,R18,R19,R20,R21,R31,R34,R35,R36,R37,R38,R39,R40,R42 | 22 | SMD | 10k 1% 0402 | Resistor_SMD:R_0402_1005Metric | 10k,10k 1%
Bourns | CR0402-FX-8251GLF | R5 | 1 | SMD | 8.25k 1% 0402 | Resistor_SMD:R_0402_1005Metric | 8.25k 1%
Vishay | CRCW040212K4FKED | R6 | 1 | SMD | 12.4k 1% 0402 | Resistor_SMD:R_0402_1005Metric | 12.4k 1%
TE Connectivity / Holsworthy | CRGCQ0402J100K | R9,R10,R11 | 3 | SMD | 100k 5% 0402 | Resistor_SMD:R_0402_1005Metric | 100k
TE Connectivity / Holsworthy | CRGCQ0402J4K7 | R12,R13,R14,R32 | 4 | SMD | 4.7k 5% 0402 | Resistor_SMD:R_0402_1005Metric | 4.7k
Vishay | CRCW04021K00FKEE | R22,R23,R24,R47 | 4 | SMD | 1k 1% 0402 | Resistor_SMD:R_0402_1005Metric | 1k,1k 1%
YAGEO | PE1206FRE470R039L | R25,R41 | 2 | SMD | 39m 1% 1206 | Resistor_SMD:R_1206_3216Metric | 39m
Bourns | CR0201AFW-1000GAS | R26 | 1 | SMD | 100 1% 0201 | Resistor_SMD:R_0201_0603Metric | 100
Bourns | ERA-2AEB202X | R27,R28,R29 | 3 | SMD | 2k 0402 | Resistor_SMD:R_0402_1005Metric | 2k
YAGEO | AC0402FR-0721KL | R30 | 1 | SMD | 21k 1% 0402 | Resistor_SMD:R_0402_1005Metric | 21k 1%
Vishay | CRCW040230K9FKEDC | R33 | 1 | SMD | 30.9k 1% 0402 | Resistor_SMD:R_0402_1005Metric | 30.9k 1%
YAGEO | RL1206FR-070R022L | R43 | 1 | SMD | 22m 1% 1206 | Resistor_SMD:R_1206_3216Metric | 22m
YAGEO | PA1206FRM670R002L | R44 | 1 | SMD | 2m 1% 1206 | Resistor_SMD:R_1206_3216Metric | 2m
TE Connectivity / Holsworthy | CRGCQ0402J3K3 | R45,R46 | 2 | SMD | 3.3k 5% 0402 | Resistor_SMD:R_0402_1005Metric | 3.3k
Texas Instruments | TPS565242DRLR | U1 | 1 | SMD |  | ECAP5-DPROC:TI_DRL0006A | TPS565242DRLR
Texas Instruments | TPS562202DRLR | U2,U3,U4 | 3 | SMD |  | ECAP5-DPROC:TI_DRL0006A | TPS562202DRLR
Texas Instruments | LM3880MFX-1AA/NOPB | U5 | 1 | SMD |  | ECAP5-DPROC:LM3880 | LM3880MF*-1AA
Lattice | LFE5U-85F-6BG756C | U6 | 1 | SMD |  | ECAP5-DPROC:LFE5U-85F-_BG756C | LFE5U-85F-*BG756*
Renesas Electronics | XLH335040.000000I | U7 | 1 | SMD | 40MHz Low Phase Noise Quartz-based PLL Oscillator | ECAP5-DPROC:XLH335040.000000I | XLH335040.000000I
Winbond | W25Q128JVPIQ TR | U8 | 1 | SMD | 3V 128M-BIT SERIAL FLASH MEMORY WITH DUAL/QUAD SPI & QPI & DTR | ECAP5-DPROC:W25Q128JVP | W25Q128JVPIQ
ISSI | IS61WV25616BLL-10BLI | U9 | 1 | SMD | 256K x 16 HIGH SPEED ASYNCHRONOUS CMOS STATIC RAM | ECAP5-DPROC:IS61WV25616BLL-_BLI | IS61WV25616BLL-*BLI
ISSI | IS42S16160J-7BLI | U10,U13 | 2 | SMD | 16Meg x16 256Mb SYNCHRONOUS DRAM | ECAP5-DPROC:IS42S16160J-_BL | IS42S16160J-*BL
ISSI | IS43DR86400E-25DBL | U11 | 1 | SMD | 64Mx8 DDR2 DRAM | ECAP5-DPROC:IS43DR86400E | IS43DR86400E
Alliance Memory | ASFC4G31M-51BIN | U12 | 1 | SMD | 4GB eMMC module | ECAP5-DPROC:ASFC4G31M-51BIN | ASFC4G31M-51*
Texas Instruments | INA219AIDCNR | U14,U16,U17,U18 | 4 | SMD | Zero-Drift, Bidirectional Current/Power Monitor (0-26V) With I2C Interface, SOT-23-8 | Package_TO_SOT_SMD:SOT-23-8 | INA219xxDCN
Texas Instruments | TLV76033DBZR | U15 | 1 | SMD | 100-mA, 30-V, Fixed-Output, Linear-Voltage Regulator | ECAP5-DPROC:TLV760 | TLV760

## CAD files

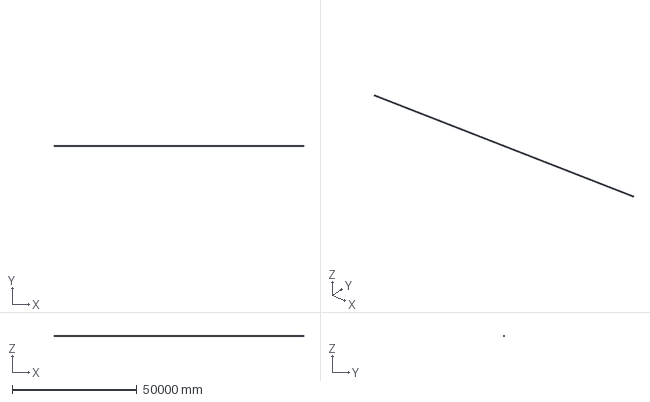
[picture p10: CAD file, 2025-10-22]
docs/simulations/test.step
100000.0 x 400.0 x 35.0 mm

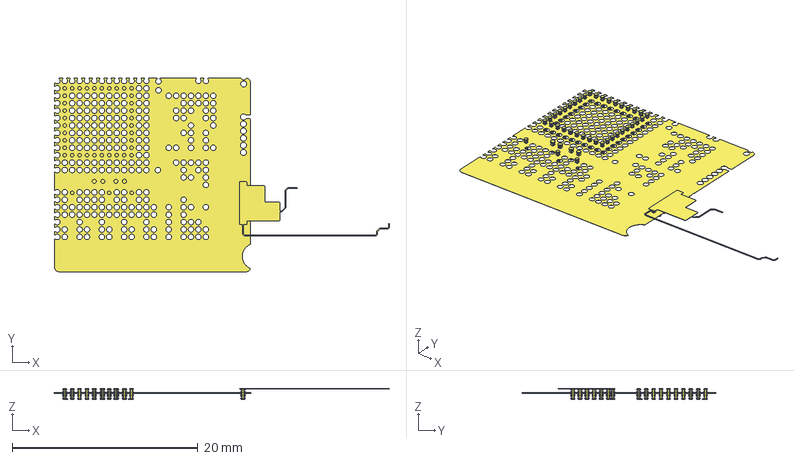
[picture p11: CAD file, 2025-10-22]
docs/simulations/plane-1v1.step
36.1 x 20.9 x 1.18 mm

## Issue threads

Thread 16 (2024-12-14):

🎨 Add signal types to schematic symbols

cchaine, 2024-12-14:
Signal types stall be assez to the schematic symbols.

Closed 2024-12-27.

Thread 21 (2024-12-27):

🐛 Add missing LVDS termination for IO connector differential pairs

cchaine, 2024-12-27:

cchaine, 2025-02-22:
ECP5's internal termination will be used.

Closed 2025-02-22.

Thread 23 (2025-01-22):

⚡ Use Kicanvas instead of schematic screenshots in design document

cchaine, 2025-01-22:
The design document's schematic screenshots shall be replaced by embedding KiCanvas.

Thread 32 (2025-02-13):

🔄 Replace the eMMC IC

cchaine, 2025-02-13:
The current eMMC IC is no longer available and the replacement `THGBMUG6C1LBAIL` doesn't provide any data sheet.

A replacing 8gb eMMC IC shall be chosen and used.

Closed 2025-02-22.

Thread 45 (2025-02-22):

✨ Add footprint for oscillator

cchaine, 2025-02-22:

Closed 2025-04-07.

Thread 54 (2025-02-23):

✨ Replace some LVDS diff pairs with 3v3 single-ended signals

cchaine, 2025-02-23:
LVDS differential pairs will be used to interact with other FPGAs.

To be able to interface the board with other ICs, some LVDS differential pairs shall be replaced with 3v3 single-ended signals.

cchaine, 2025-02-23:
- [x] Update the design document
- [x] Update the connector symbol
- [x] Update the nets on connector side
- [ ] Use Bank 6 for single ended signals
- [ ] Change Bank 6 supply to 3v3
- [ ] Use Bank 4 if needed for single ended signals
- [ ] Use Bank 2 and Bank 3 AB pins for LVDS pairs.

Closed 2025-03-01.

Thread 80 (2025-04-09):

♻  Replace power supply ics

cchaine, 2025-04-09:
- [x] Find smaller inductors
- [x] Update the documentation

Closed 2025-04-14.

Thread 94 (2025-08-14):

🐛 Add pull-up resistor on reset IO pin

cchaine, 2025-08-14:

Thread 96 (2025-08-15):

🐛 Fix pinout in documentation

cchaine, 2025-08-15:
The pinout in the documentation is not up to date with the board (IO differential pair +/- swapping)

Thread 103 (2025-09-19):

🚑️ Fix 0.10mm not equal to 4mil

cchaine, 2025-09-19:
JLCPCB has clearances defined as 4mil = 0.10mm whereas 4mil > 0.10mm.

The design rules shall be updated to 4mil and the routing fixed.

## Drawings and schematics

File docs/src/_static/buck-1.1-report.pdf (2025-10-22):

## WEBENCH ® Design Report

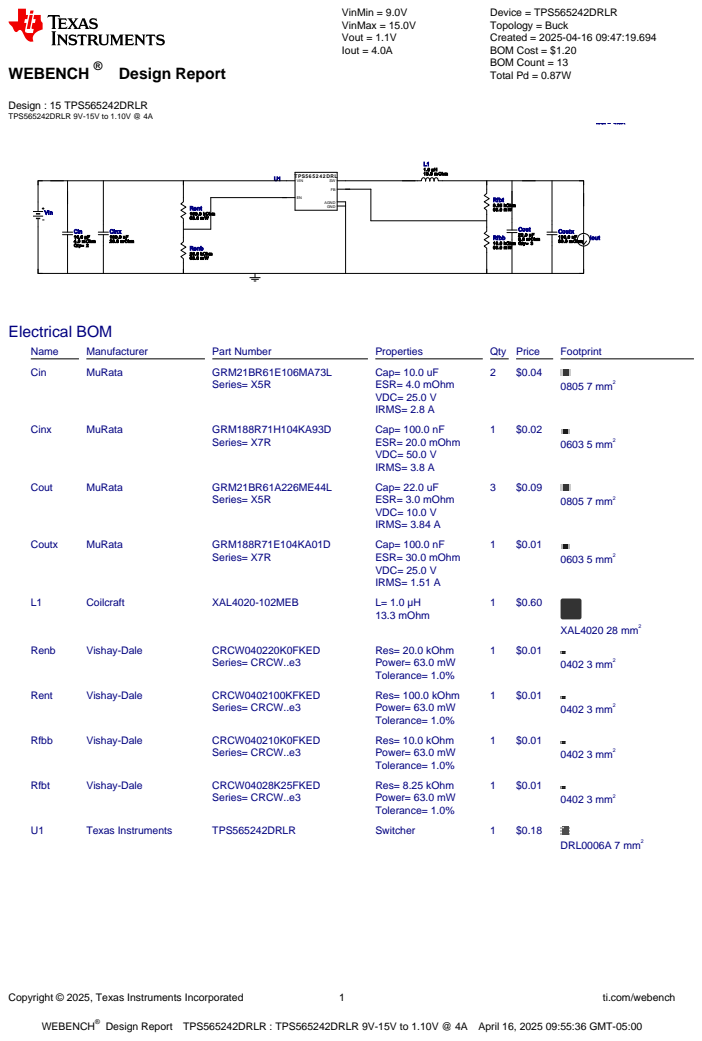
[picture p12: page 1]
Copyright © 2025, Texas Instruments Incorporated; ti.com/webench; WEBENCH®; Design : 15 TPS565242DRLR TPS565242DRLR 9V-15V to 1.10V @ 4A; VinMin = 9.0V VinMax = 15.0V Vout = 1.1V Iout = 4.0A; Device = TPS565242DRLR Topology = Buck Created = 2025-04-16 09:47:19.694 BOM Cost = $1.20 BOM Count = 13 Total Pd = 0.87W; Rfbt 8.25 kOhm; Rfbb 10.0 kOhm 63.0 m W; Coutx 100.0 nF 30.0 m Ohm; Cin 10.0 µF 4.0 m Ohm Qty= 2; L1 1.0 µH 13.3 m Ohm; Cout 22.0 µF; 3.0 m Ohm Qty= 3; TPS5 6 5 2 4 2 DRL; VIN; GND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

Design Report TPS565242DRLR : TPS565242DRLR 9V-15V to 1.10V @ 4A April 16, 2025 09:55:36 GMT-05:00

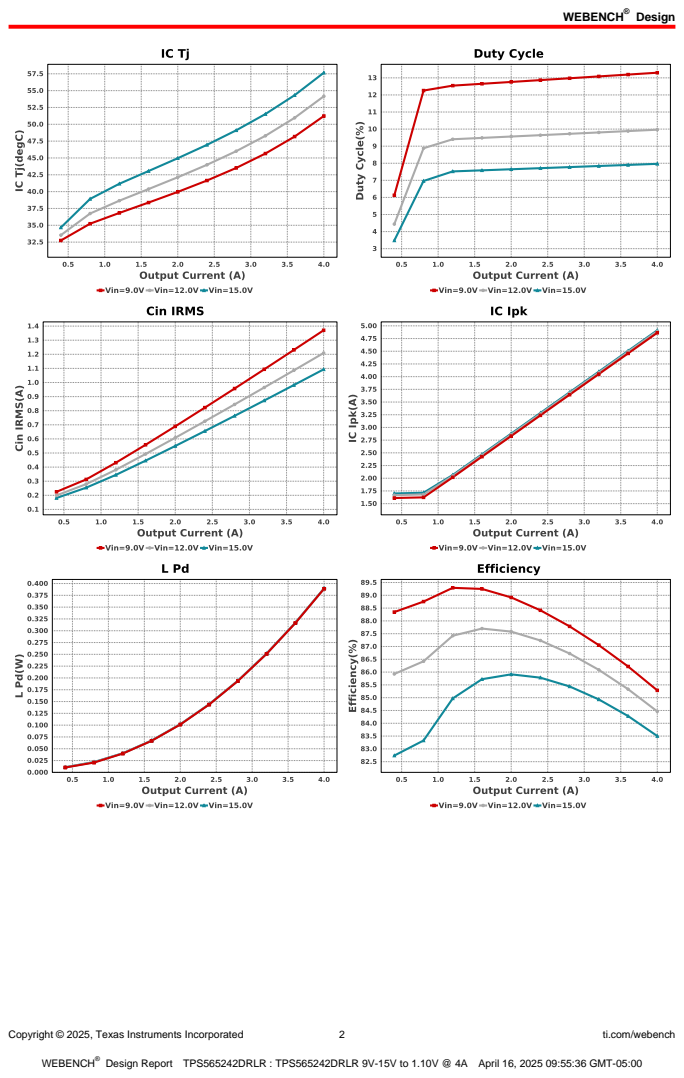
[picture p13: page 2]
Design; Copyright © 2025, Texas Instruments Incorporated; ti.com/webench

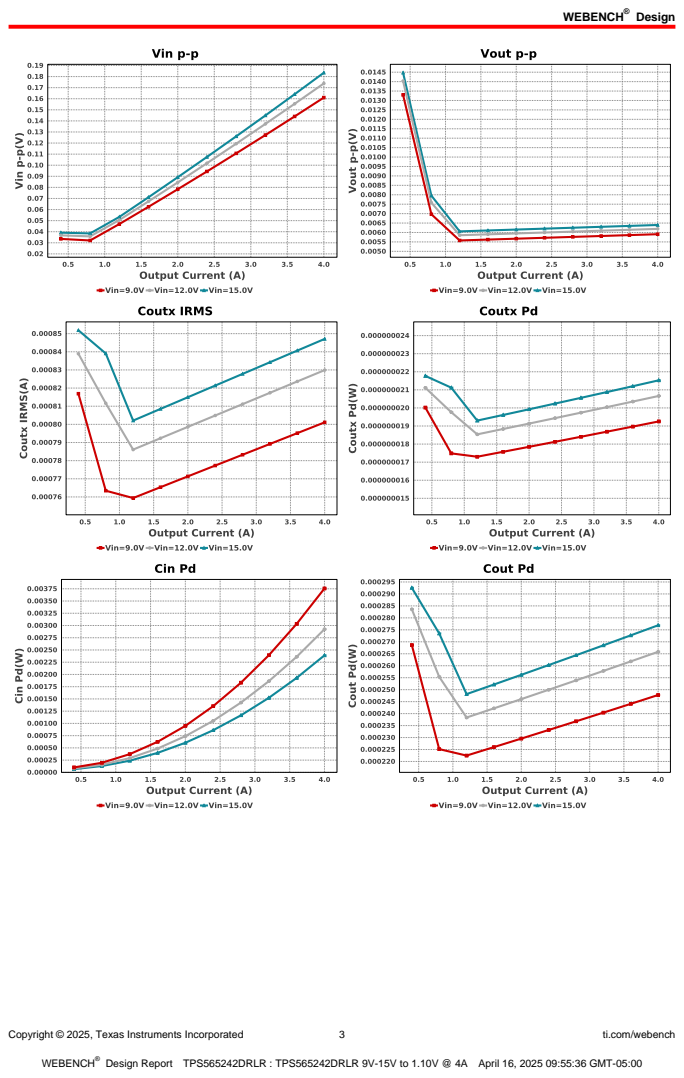
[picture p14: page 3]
Copyright © 2025, Texas Instruments Incorporated; ti.com/webench

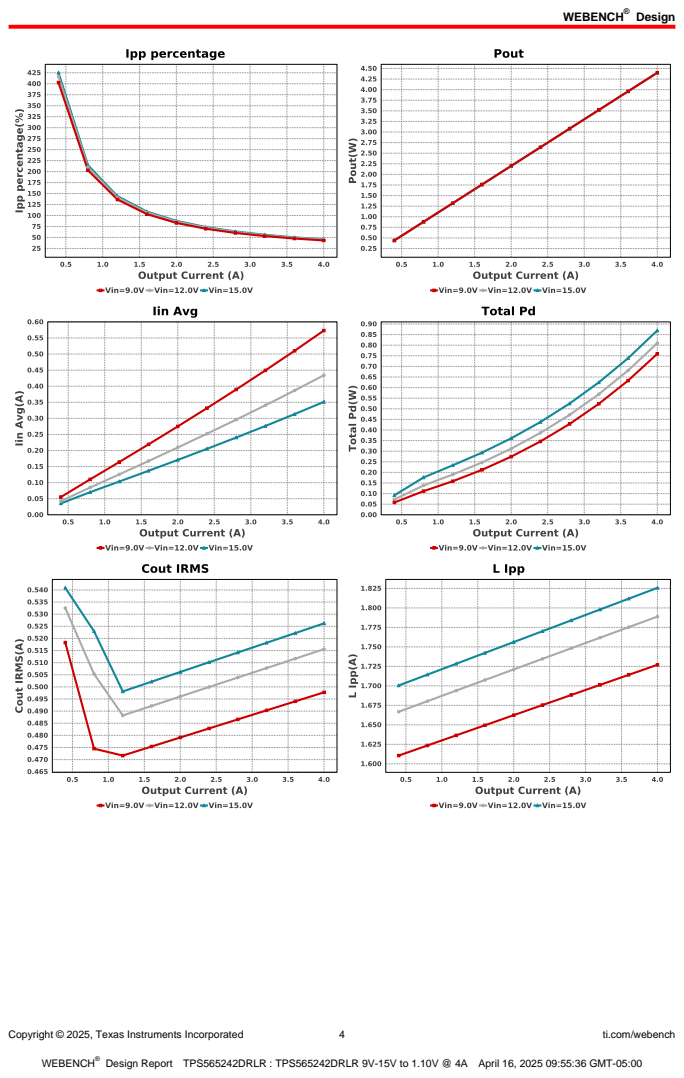
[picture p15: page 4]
Copyright © 2025, Texas Instruments Incorporated; ti.com/webench

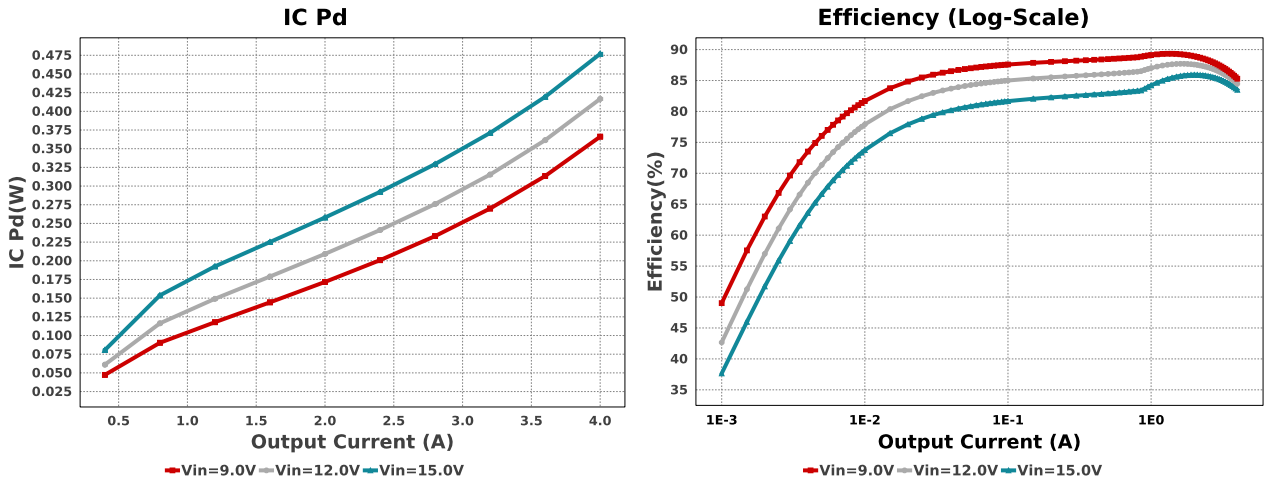
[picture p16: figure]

Copyright © 2025, Texas Instruments Incorporated | 5 | ti.com/webench

## Operating Values

# | Name | Value | Category | Description

1. BOM Count | 13 | Total Design BOM count
2. Total BOM | $1.2 | Total BOM Cost
3. Cin IRMS | 1.093 A | Capacitor | Input capacitor RMS ripple current
4. Cin Pd | 2.39 mW | Capacitor | Input capacitor power dissipation
5. Cout IRMS | 526.21 mA | Capacitor | Output capacitor RMS ripple current
6. Cout Pd | 276.9 µW | Capacitor | Output capacitor power dissipation
7. Coutx IRMS | 847.086 µA | Capacitor | Output capacitor_x RMS ripple current
8. Coutx Pd | 21.527 nW | Capacitor | Output capacitor_x power loss
9. IC Ipk | 4.913 A | IC | Peak switch current in IC
10. IC Pd | 476.92 mW | IC | IC power dissipation
11. IC Tj | 57.661 degC | IC | IC junction temperature
12. IC Tolerance | 11.0 mV | IC | IC Feedback Tolerance
13. ICThetaJA Effective | 58.0 degC/W | IC | IC junction-to-ambient thermal resistance with TI EVM
14. Iin Avg | 351.29 mA | IC | Average input current
15. Ipp percentage | 45.644 % | Inductor | Inductor ripple current percentage (with respect to average inductor
| | | | current)
16. L Ipp | 1.826 A | Inductor | Peak-to-peak inductor ripple current
17. L Pd | 389.69 mW | Inductor | Inductor power dissipation
18. Cin Pd | 2.39 mW | Power | Input capacitor power dissipation
19. Cout Pd | 276.9 µW | Power | Output capacitor power dissipation
20. Coutx Pd | 21.527 nW | Power | Output capacitor_x power loss
21. IC Pd | 476.92 mW | Power | IC power dissipation
22. L Pd | 389.69 mW | Power | Inductor power dissipation
23. Total Pd | 869.337 mW | Power | Total Power Dissipation
24. Duty Cycle | 7.966 % | System
| | | Information | Duty cycle
25. Efficiency | 83.502 % | System
| | | Information | Steady state efficiency
26. FootPrint | 90.0 mm² | System
| | | Information | Total Foot Print Area of BOM components
27. Frequency | 600.678 kHz | System
| | | Information | Switching frequency
28. Iout | 4.0 A | System
| | | Information | Iout operating point
29. Mode | CCM | System
| | | Information | Conduction Mode
30. Pout | 4.4 W | System
| | | Information | Total output power
31. Vin | 15.0 V | System
| | | Information | Vin operating point
32. Vin p-p | 183.478 mV | System
| | | Information | Peak-to-peak input voltage
33. Vout | 1.1 V | System
| | | Information | Operational Output Voltage
34. Vout Actual | 1.095 V | System
| | | Information | Vout Actual calculated based on selected voltage divider resistors
35. Vout Tolerance | 2.763 % | System
| | | Information | Vout Tolerance based on IC Tolerance (no load) and voltage divider resistors if applicable
36. Vout p-p | 6.397 mV | System
| | | Information | Peak-to-peak output ripple voltage

Copyright © 2025, Texas Instruments Incorporated | 6 | ti.com/webench

## Design Inputs

Name | Value | Description
Iout | 4.0 | Maximum Output Current
VinMax | 15.0 | Maximum input voltage
VinMin | 9.0 | Minimum input voltage
Vout | 1.1 | Output Voltage
base_pn | TPS565242 | Base Product Number
source | DC | Input Source Type
Ta | 30.0 | Ambient temperature


Copyright © 2025, Texas Instruments Incorporated | 7 | ti.com/webench

## Assembly
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

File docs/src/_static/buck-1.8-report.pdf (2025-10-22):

## WEBENCH ® Design Report

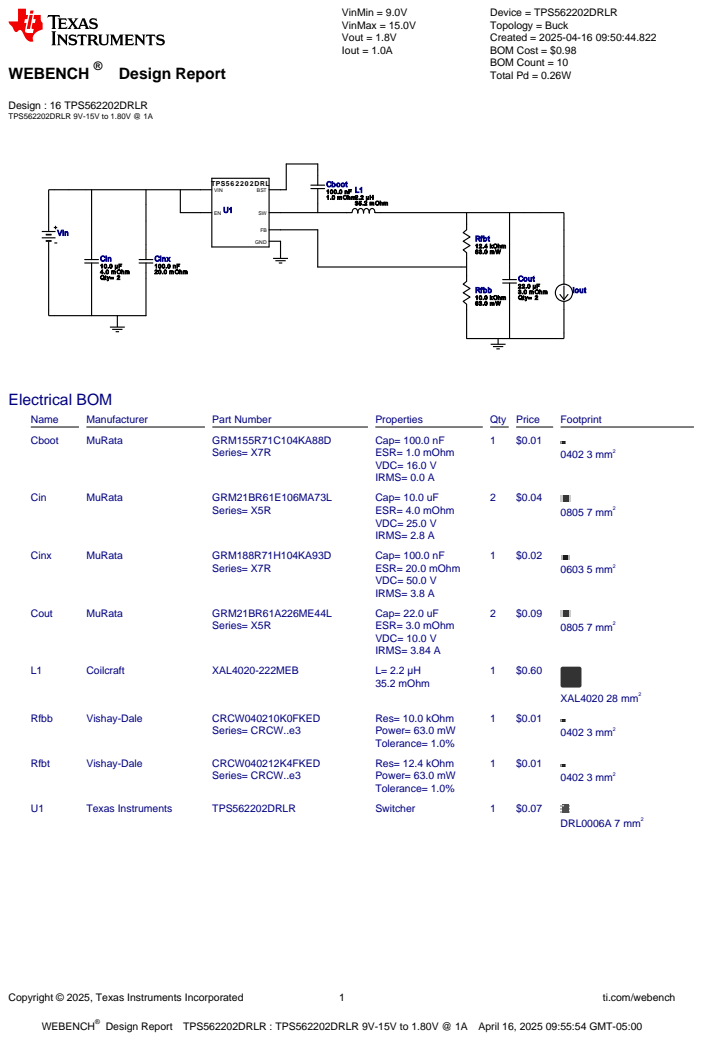
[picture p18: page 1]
Copyright © 2025, Texas Instruments Incorporated; ti.com/webench; WEBENCH®; Design : 16 TPS562202DRLR TPS562202DRLR 9V-15V to 1.80V @ 1A; VinMin = 9.0V VinMax = 15.0V Vout = 1.8V Iout = 1.0A; Device = TPS562202DRLR Topology = Buck Created = 2025-04-16 09:50:44.822 BOM Cost = $0.98 BOM Count = 10 Total Pd = 0.26W; Cboot 100.0 nF 1.0 m Ohm; Cout 22.0 µF 3.0 m Ohm Qty= 2; Cin 10.0 µF 4.0 m Ohm Qty= 2; Cinx 100.0 nF 20.0 m Ohm; Rfbb 10.0 kOhm 63.0 m W; Rfbt 12.4 kOhm 63.0 m W; L1 2.2 µH 35.2 m Ohm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

Design Report TPS562202DRLR : TPS562202DRLR 9V-15V to 1.80V @ 1A April 16, 2025 09:55:54 GMT-05:00

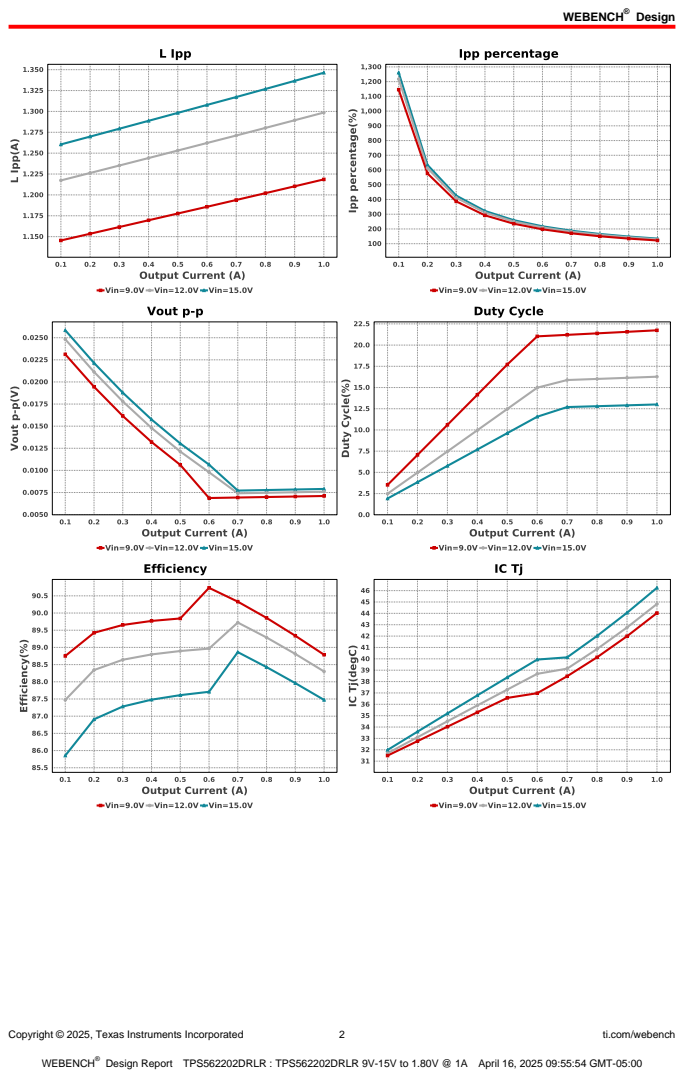
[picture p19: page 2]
Design; Copyright © 2025, Texas Instruments Incorporated; ti.com/webench

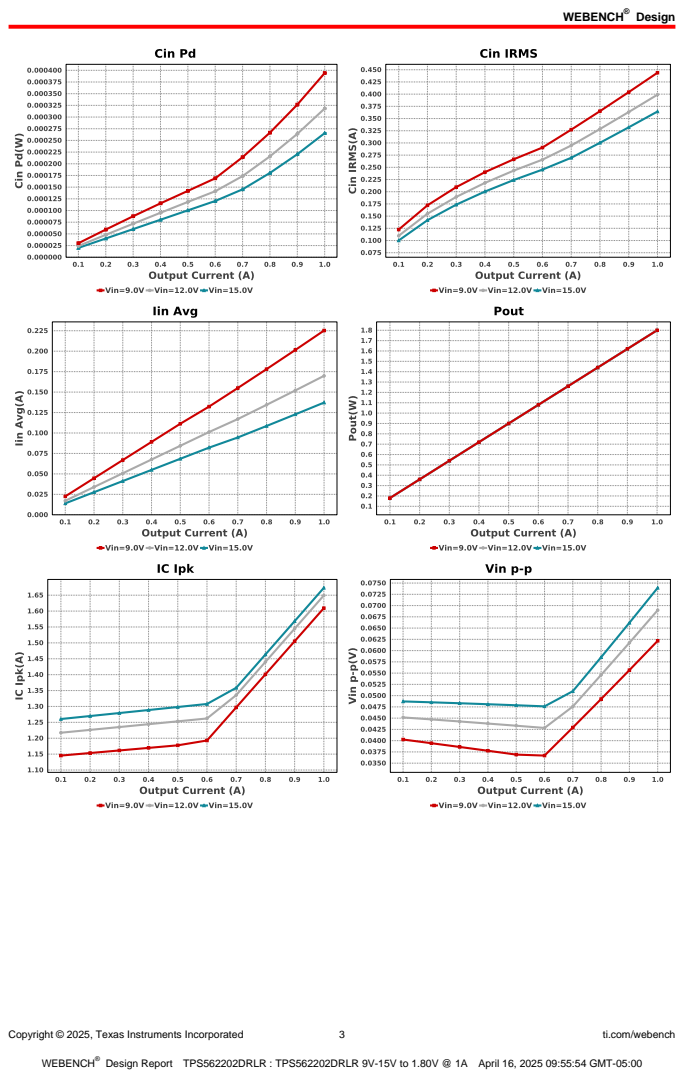
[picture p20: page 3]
Copyright © 2025, Texas Instruments Incorporated; ti.com/webench

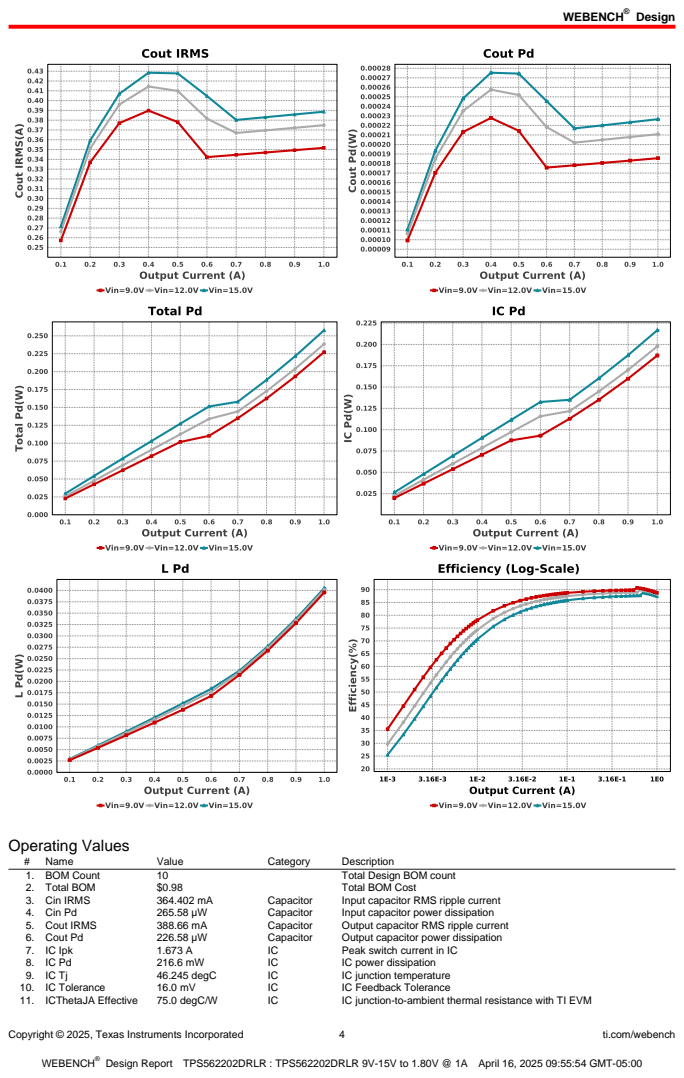
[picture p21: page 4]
Copyright © 2025, Texas Instruments Incorporated; ti.com/webench; Operating Values; Name; Value; Category; Description; 1. BOM Count; Total Design BOM count; 2. Total BOM; Total BOM Cost; 3. Cin IRMS; Capacitor; Input capacitor RMS ripple current; 4. Cin Pd; Input capacitor power dissipation; 5. Cout IRMS; Output capacitor RMS ripple current; 6. Cout Pd; Output capacitor power dissipation; 7. IC Ipk; Peak switch current in IC; IC power dissipation; 46.245 degC; IC junction temperature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

Copyright © 2025, Texas Instruments Incorporated | 5 | ti.com/webench
# | Name | Value | Category | Description

12. Iin Avg | 137.18 mA | IC | Average input current
13. Ipp percentage | 134.636 % | Inductor | Inductor ripple current percentage (with respect to average inductor
| | | | current)
14. L Ipp | 1.346 A | Inductor | Peak-to-peak inductor ripple current
15. L Pd | 40.517 mW | Inductor | Inductor power dissipation
16. Cin Pd | 265.58 µW | Power | Input capacitor power dissipation
17. Cout Pd | 226.58 µW | Power | Output capacitor power dissipation
18. IC Pd | 216.6 mW | Power | IC power dissipation
19. L Pd | 40.517 mW | Power | Inductor power dissipation
20. Total Pd | 257.748 mW | Power | Total Power Dissipation
21. Duty Cycle | 13.006 % | System
| | | Information | Duty cycle
22. Efficiency | 87.474 % | System
| | | Information | Steady state efficiency
23. FootPrint | 76.0 mm² | System
| | | Information | Total Foot Print Area of BOM components
24. Frequency | 570.068 kHz | System
| | | Information | Switching frequency
25. Iout | 1.0 A | System
| | | Information | Iout operating point
26. Mode | CCM | System
| | | Information | Conduction Mode
27. Pout | 1.8 W | System
| | | Information | Total output power
28. Vin | 15.0 V | System
| | | Information | Vin operating point
29. Vin p-p | 73.941 mV | System
| | | Information | Peak-to-peak input voltage
30. Vout | 1.8 V | System
| | | Information | Operational Output Voltage
31. Vout Actual | 1.801 V | System
| | | Information | Vout Actual calculated based on selected voltage divider resistors
32. Vout Tolerance | 3.131 % | System
| | | Information | Vout Tolerance based on IC Tolerance (no load) and voltage divider resistors if applicable
33. Vout p-p | 7.902 mV | System
| | | Information | Peak-to-peak output ripple voltage

## Design Inputs

Name | Value | Description
Iout | 1.0 | Maximum Output Current
VinMax | 15.0 | Maximum input voltage
VinMin | 9.0 | Minimum input voltage
Vout | 1.8 | Output Voltage
| base_pn | | TPS562202 | Base Product Number
source | DC | Input Source Type
Ta | 30.0 | Ambient temperature


Copyright © 2025, Texas Instruments Incorporated | 6 | ti.com/webench

## Assembly

## Component Testing

Some published data on components in datasheets such as Capacitor ESR and Inductor DC resistance is based on conservative values that will guarantee that the components always exceed the specification. For design purposes it is usually better to work with typical values. Since this data is not always available it is a good practice to measure the Capacitance and ESR values of Cin and Cout, and the inductance and DC resistance of L1 before assembly of the board. Any large discrepancies in values should be electrically simulated in WEBENCH to check for instabilities and thermally simulated in WebTHERM to make sure critical temperatures are not exceeded.
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

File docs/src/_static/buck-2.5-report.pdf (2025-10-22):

## WEBENCH ® Design Report

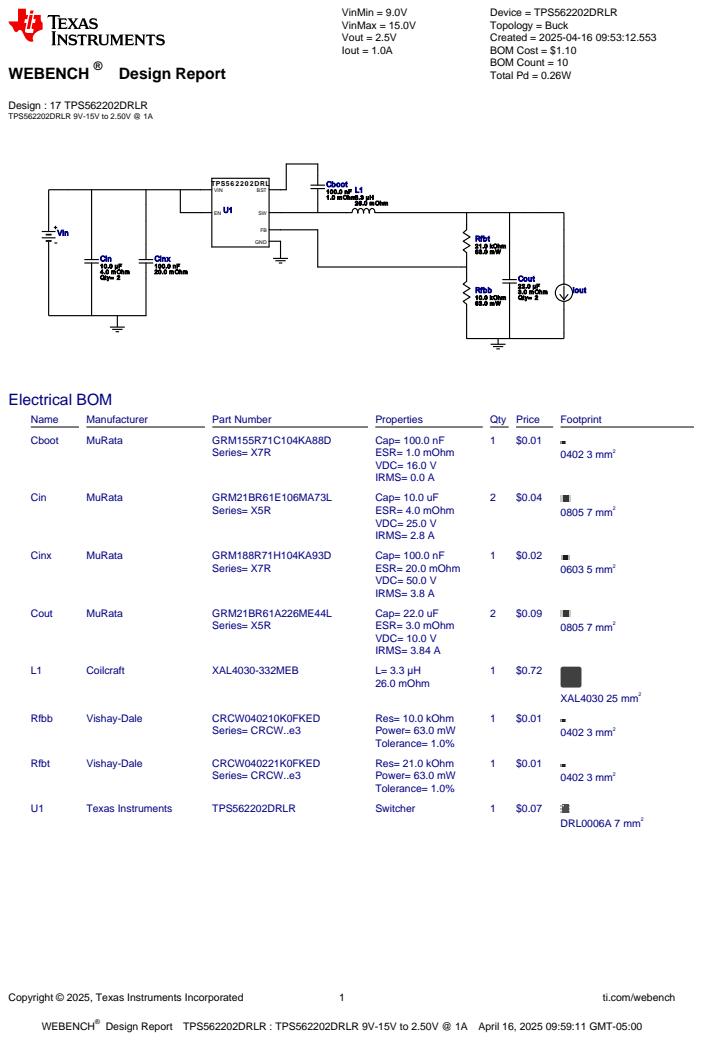
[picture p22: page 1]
Copyright © 2025, Texas Instruments Incorporated; ti.com/webench; WEBENCH®; Design : 17 TPS562202DRLR TPS562202DRLR 9V-15V to 2.50V @ 1A; VinMin = 9.0V VinMax = 15.0V Vout = 2.5V Iout = 1.0A; Device = TPS562202DRLR Topology = Buck Created = 2025-04-16 09:53:12.553 BOM Cost = $1.10 BOM Count = 10 Total Pd = 0.26W; Cboot 100.0 nF 1.0 m Ohm; Cout 22.0 µF 3.0 m Ohm Qty= 2; Cin 10.0 µF 4.0 m Ohm Qty= 2; Cinx 100.0 nF 20.0 m Ohm; Rfbb 10.0 kOhm 63.0 m W; Rfbt 21.0 kOhm 63.0 m W; L1 3.3 µH 26.0 m Ohm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

Design Report TPS562202DRLR : TPS562202DRLR 9V-15V to 2.50V @ 1A April 16, 2025 09:59:11 GMT-05:00

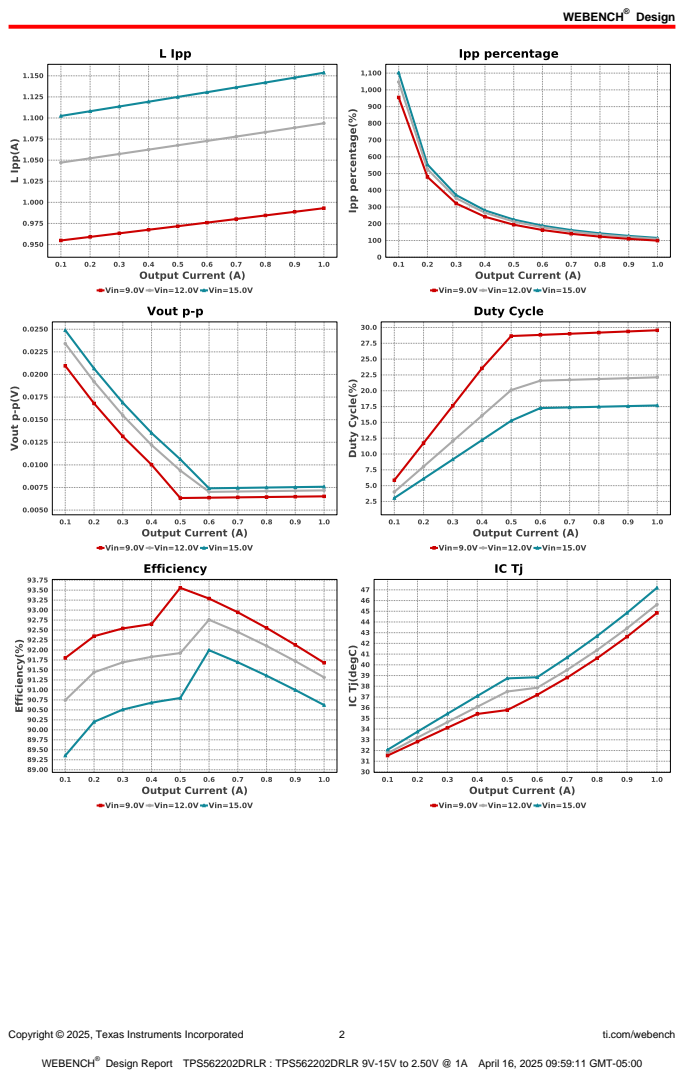
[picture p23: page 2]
Design; Copyright © 2025, Texas Instruments Incorporated; ti.com/webench

Copyright © 2025, Texas Instruments Incorporated; ti.com/webench

Copyright © 2025, Texas Instruments Incorporated; ti.com/webench; Operating Values; Name; Value; Category; Description; 1. BOM Count; Total Design BOM count; 2. Total BOM; Total BOM Cost; 3. Cin IRMS; Capacitor; Input capacitor RMS ripple current; 4. Cin Pd; Input capacitor power dissipation; 5. Cout IRMS; Output capacitor RMS ripple current; 6. Cout Pd; Output capacitor power dissipation; 7. IC Ipk; Peak switch current in IC; IC power dissipation; 47.187 degC; IC junction temperature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

Copyright © 2025, Texas Instruments Incorporated | 5 | ti.com/webench
# | Name | Value | Category | Description

12. Iin Avg | 183.92 mA | IC | Average input current
13. Ipp percentage | 115.366 % | Inductor | Inductor ripple current percentage (with respect to average inductor
| | | | current)
14. L Ipp | 1.154 A | Inductor | Peak-to-peak inductor ripple current
15. L Pd | 28.884 mW | Inductor | Inductor power dissipation
16. Cin Pd | 330.25 µW | Power | Input capacitor power dissipation
17. Cout Pd | 166.37 µW | Power | Output capacitor power dissipation
18. IC Pd | 229.16 mW | Power | IC power dissipation
19. L Pd | 28.884 mW | Power | Inductor power dissipation
20. Total Pd | 258.748 mW | Power | Total Power Dissipation
21. Duty Cycle | 17.676 % | System
| | | Information | Duty cycle
22. Efficiency | 90.621 % | System
| | | Information | Steady state efficiency
23. FootPrint | 72.0 mm² | System
| | | Information | Total Foot Print Area of BOM components
24. Frequency | 570.286 kHz | System
| | | Information | Switching frequency
25. Iout | 1.0 A | System
| | | Information | Iout operating point
26. Mode | CCM | System
| | | Information | Conduction Mode
27. Pout | 2.5 W | System
| | | Information | Total output power
28. Vin | 15.0 V | System
| | | Information | Vin operating point
29. Vin p-p | 93.914 mV | System
| | | Information | Peak-to-peak input voltage
30. Vout | 2.5 V | System
| | | Information | Operational Output Voltage
31. Vout Actual | 2.492 V | System
| | | Information | Vout Actual calculated based on selected voltage divider resistors
32. Vout Tolerance | 3.386 % | System
| | | Information | Vout Tolerance based on IC Tolerance (no load) and voltage divider resistors if applicable
33. Vout p-p | 7.583 mV | System
| | | Information | Peak-to-peak output ripple voltage

## Design Inputs

Name | Value | Description
Iout | 1.0 | Maximum Output Current
VinMax | 15.0 | Maximum input voltage
VinMin | 9.0 | Minimum input voltage
Vout | 2.5 | Output Voltage
| base_pn | | TPS562202 | Base Product Number
source | DC | Input Source Type
Ta | 30.0 | Ambient temperature


Copyright © 2025, Texas Instruments Incorporated | 6 | ti.com/webench

## Assembly

## Component Testing

Some published data on components in datasheets such as Capacitor ESR and Inductor DC resistance is based on conservative values that will guarantee that the components always exceed the specification. For design purposes it is usually better to work with typical values. Since this data is not always available it is a good practice to measure the Capacitance and ESR values of Cin and Cout, and the inductance and DC resistance of L1 before assembly of the board. Any large discrepancies in values should be electrically simulated in WEBENCH to check for instabilities and thermally simulated in WebTHERM to make sure critical temperatures are not exceeded.
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

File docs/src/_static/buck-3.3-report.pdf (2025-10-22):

## WEBENCH ® Design Report

Copyright © 2025, Texas Instruments Incorporated; ti.com/webench; WEBENCH®; Design : 18 TPS562202DRLR TPS562202DRLR 9V-15V to 3.30V @ 1A; VinMin = 9.0V VinMax = 15.0V Vout = 3.3V Iout = 1.0A; Device = TPS562202DRLR Topology = Buck Created = 2025-04-16 09:59:04.265 BOM Cost = $1.11 BOM Count = 11 Total Pd = 0.32W; Cboot 100.0 nF 1.0 m Ohm; Cout 22.0 µF 3.0 m Ohm Qty= 2; Cff 22.0 pF; Cin 10.0 µF 4.0 m Ohm Qty= 2; Cinx 100.0 nF 20.0 m Ohm; Rfbb 10.0 kOhm 63.0 m W; Rfbt 30.9 kOhm 63.0 m W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

Design Report TPS562202DRLR : TPS562202DRLR 9V-15V to 3.30V @ 1A April 16, 2025 10:04:56 GMT-05:00

Design; Copyright © 2025, Texas Instruments Incorporated; ti.com/webench

Copyright © 2025, Texas Instruments Incorporated; ti.com/webench

Copyright © 2025, Texas Instruments Incorporated; ti.com/webench; Operating Values; Name; Value; Category; Description; 1. BOM Count; Total Design BOM count; 2. Total BOM; Total BOM Cost; 3. Cin IRMS; Capacitor; Input capacitor RMS ripple current; 4. Cin Pd; Input capacitor power dissipation; 5. Cout IRMS; Output capacitor RMS ripple current; 6. Cout Pd; Output capacitor power dissipation; 7. IC Ipk; Peak switch current in IC; IC power dissipation; 51.979 degC; IC junction temperature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

Copyright © 2025, Texas Instruments Incorporated | 5 | ti.com/webench
# | Name | Value | Category | Description

12. Iin Avg | 241.62 mA | IC | Average input current
13. Ipp percentage | 140.593 % | Inductor | Inductor ripple current percentage (with respect to average inductor
| | | | current)
14. L Ipp | 1.406 A | Inductor | Peak-to-peak inductor ripple current
15. L Pd | 30.283 mW | Inductor | Inductor power dissipation
16. Cin Pd | 430.63 µW | Power | Input capacitor power dissipation
17. Cout Pd | 247.08 µW | Power | Output capacitor power dissipation
18. IC Pd | 293.05 mW | Power | IC power dissipation
19. L Pd | 30.283 mW | Power | Inductor power dissipation
20. Total Pd | 324.266 mW | Power | Total Power Dissipation
21. Duty Cycle | 23.047 % | System
| | | Information | Duty cycle
22. Efficiency | 91.053 % | System
| | | Information | Steady state efficiency
23. FootPrint | 75.0 mm² | System
| | | Information | Total Foot Print Area of BOM components
24. Frequency | 570.295 kHz | System
| | | Information | Switching frequency
25. Iout | 1.0 A | System
| | | Information | Iout operating point
26. Mode | CCM | System
| | | Information | Conduction Mode
27. Pout | 3.3 W | System
| | | Information | Total output power
28. Vin | 15.0 V | System
| | | Information | Vin operating point
29. Vin p-p | 114.02 mV | System
| | | Information | Peak-to-peak input voltage
30. Vout | 3.3 V | System
| | | Information | Operational Output Voltage
31. Vout Actual | 3.288 V | System
| | | Information | Vout Actual calculated based on selected voltage divider resistors
32. Vout Tolerance | 3.547 % | System
| | | Information | Vout Tolerance based on IC Tolerance (no load) and voltage divider resistors if applicable
33. Vout p-p | 10.788 mV | System
| | | Information | Peak-to-peak output ripple voltage

## Design Inputs

Name | Value | Description
Iout | 1.0 | Maximum Output Current
VinMax | 15.0 | Maximum input voltage
VinMin | 9.0 | Minimum input voltage
Vout | 3.3 | Output Voltage
| base_pn | | TPS562202 | Base Product Number
source | DC | Input Source Type
Ta | 30.0 | Ambient temperature


Copyright © 2025, Texas Instruments Incorporated | 6 | ti.com/webench

## Assembly

## Component Testing

Some published data on components in datasheets such as Capacitor ESR and Inductor DC resistance is based on conservative values that will guarantee that the components always exceed the specification. For design purposes it is usually better to work with typical values. Since this data is not always available it is a good practice to measure the Capacitance and ESR values of Cin and Cout, and the inductance and DC resistance of L1 before assembly of the board. Any large discrepancies in values should be electrically simulated in WEBENCH to check for instabilities and thermally simulated in WebTHERM to make sure critical temperatures are not exceeded.
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

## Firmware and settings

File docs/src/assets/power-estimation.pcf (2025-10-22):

[[Info]]
_PARENT: none
_FILE_FORMAT: 1.00
_DATA_VALUES: 1.00
_STATUS: Advanced
_FAMILY: sa5p00m

[[Project]]
DesignName: Untitled
Version: 1.0
Family: ECP5U
Device: LFE5U-85F
Package: CABGA756
Operating: Commercial
Performance: -8
PartName: LFE5U-85F-8BG756C

[[Settings]]
EstimationMode: Medium
ProcessType: Worst
SoftwareMode: Estimation
SectionY: Total Power
SectionX: Vcc
SectionLowerLimit: 1.0450
SectionUpperLimit: 1.1650
SectionResolution: 0.0240
TempAmbY: Total Power
TempAmbX: Ambient Temperature
TempAmbLowerLimit: -40.0000
TempAmbUpperLimit: 125.0000
TempAmbResolution: 33.0000
FreqY: Total Power
FreqX: clk_1
FreqLowerLimit: 0.0000
FreqUpperLimit: 100.0000
FreqAmbResolution: 20.0000
PowerMode: Normal
DisableBandgap: false
DisablePor: false
DisableDll: false
DisableOsc: false
DisablePCSD0CH0CDRPLL: false
DisablePCSD0CH0LOS: false
DisablePCSD0CH0Rx: false
DisablePCSD0CH0Tx: false
DisablePCSD0CH1CDRPLL: false
DisablePCSD0CH1LOS: false
DisablePCSD0CH1Rx: false
DisablePCSD0CH1Tx: false
DisablePCSD1CH0CDRPLL: false
DisablePCSD1CH0LOS: false
DisablePCSD1CH0Rx: false
DisablePCSD1CH0Tx: false
DisablePCSD1CH1CDRPLL: false
DisablePCSD1CH1LOS: false
DisablePCSD1CH1Rx: false
DisablePCSD1CH1Tx: false
DisablePCSD2CH0CDRPLL: false
DisablePCSD2CH0LOS: false
DisablePCSD2CH0Rx: false
DisablePCSD2CH0Tx: false
DisablePCSD2CH1CDRPLL: false
DisablePCSD2CH1LOS: false
DisablePCSD2CH1Rx: false
DisablePCSD2CH1Tx: false
DisablePCSD3CH0CDRPLL: false
DisablePCSD3CH0LOS: false
DisablePCSD3CH0Rx: false
DisablePCSD3CH0Tx: false
DisablePCSD3CH1CDRPLL: false
DisablePCSD3CH1LOS: false
DisablePCSD3CH1Rx: false
DisablePCSD3CH1Tx: false
DisableD0TXPLL: false
DisableD1TXPLL: false
DisableD2TXPLL: false
DisableD3TXPLL: false
DisableMACOMAC2EMACA0: false
DisableMACOMAC2EMACA1: false
DisableMACOMAC2EMACA2: false
DisableMACOMAC2EMACA3: false
DisableMACOMAC2EMACB0: false
DisableMACOMAC2EMACB1: false
DisableMACOMAC2EMACB2: false
DisableMACOMAC2EMACB3: false
DisableMACOMAC2XMAC: false
DisableMACOMAC3EMACA0: false
DisableMACOMAC3EMACA1: false
DisableMACOMAC3EMACA2: false
DisableMACOMAC3EMACA3: false
DisableMACOMAC3EMACB0: false
DisableMACOMAC3EMACB1: false
DisableMACOMAC3EMACB2: false
DisableMACOMAC3EMACB3: false
DisableMACOMAC3XMAC: false
DisableMACOPCIEPCIE: false
DisableMACOSRIOEMAC0: false
DisableMACOSRIOEMAC1: false
DisableMACOSRIOEMAC2: false
DisableMACOSRIOEMAC3: false
DisableMACOSRIOSRIO: false
DisablePUSL0: false
DisablePUSL1: false
DisablePUSL2: false
DisablePUSL3: false
DisablePUSL4: false
DisablePUSL5: false
DisablePUSL6: false
DisablePUSL7: false
DisableDDRDLLBL0: false
DisableDDRDLLBL1: false
DisableDDRDLLBR0: false
DisableDDRDLLBR1: false
DisableDDRDLLTL0: false
DisableDDRDLLTL1: false
DisableDDRDLLTR0: false
DisableDDRDLLTR1: false
DisablePLLBL0: false
DisablePLLBL1: false
DisablePLLBR0: false
DisablePLLBR1: false
DisablePLLTL0: false
DisablePLLTL1: false
DisablePLLTR0: false
DisablePLLTR1: false
DisableInRd0: false
DisableInRd1: false
DisableInRd2: false
DisableInRd3: false
DisableInRd4: false
DisableInRd5: false
DisableInRd6: false
DisableInRd7: false
EnablePg0: false
EnablePg1: false
EnablePg2: false
EnablePg3: false
EnablePg4: false
EnablePg5: false
EnablePg6: false
EnablePg7: false
DisableLVDS: false
DisableLVDS1: false
DisableLVDS2: false
DisableLVDS3: false
DisableLVDS4: false
DisableLVDS5: false
DisableLVDS6: false
DisableLVDS7: false
DisableSlewrate0: false
DisableSlewrate1: false
DisableSlewrate2: false
DisableSlewrate3: false
DisableSlewrate4: false
DisableSlewrate5: false

[[Thermal]]
Airflow: 200 LFM
AmbientTemperature: 25
CustomThetaSA: -1
JunctionTemperature: 58.24
MaxSafeAmbient: 48.74
ThetaBA: 10.0
ThetaCS: 0
ThetaEffective: 7.684294872
ThetaJA: 20.59
ThetaJB: 12.88
ThetaJC: 0
ThetaSA: -1
UserThetaBA: No
UserThetaCS: No
UserThetaEffective: No
UserThetaJA: No
UserThetaJB: No
UserThetaJC: No
UserThetaSA: No
thetaBoard: Medium Board
thetaHeatSink: No Heat Sink
thetaOption: ThermalModels

[[VDPM]]
Supply = Voltage, DPM
Vcc = 1.100, 1.00
Vccaux = 2.500, 1.00
Vccio 3.3 = 3.300, 1.00
Vccio 2.5 = 2.500, 1.00
Vccio 1.8 = 1.800, 1.00
Vccio 1.5 = 1.500, 1.00
Vccio 1.35 = 1.350, 1.00
Vccio 1.2 = 1.200, 1.00
Vcchtx = 1.100, 1.00
Vcchrx = 1.100, 1.00
Vcca = 1.100, 1.00
Vccauxa = 2.500, 1.00

[[Logic]]
Clk = F, AF, LUT, RAM, RIPPLE, REG, X0, X1, X2, X6, ISB, ISBLUT, ISBCE, ISBLSR, ISBM, ISBCLK
clk_1 = 200.0000, 25.0000, 60000, 30000, 30000, 60000, 4.0219e+004, 4.0219e+004, 1.6087e+005, 8.0437e+004, 2.7000e+005, 0, 0, 0, 0, 0
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

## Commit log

2025-10-22 Add functional specification (#7)
    * Starts adding the structure of the architecture document
    * Starts adding functional requirements
    * Add overview diagram
    * Adds design requirements for the qspi memory
    * Adds design requirements for the eMMC module
    * Changes the SDRAM reference
    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
    [ddr2-pinout.csv, emmc-pinout.csv, flash-pinout.csv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]
2025-10-22 ✨ Adds a first draft of the schematic (#22)
    * Adds the kicad project
    * Adds custom title block
    * Starts adding the power schematics
    * Update the architecture document with the available components
    * Adds power sequencing ic
    * Remove high speed serdes from board requirements
    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
    [clock.kicad_sch, ddr2-pinout.csv, ddr2.kicad_sch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]
2025-10-22 📝 Replaces the architecture document with a design document (#24)
    * Starts converting the architecture document into a design document
    * Updates the structure of the document
    * Updates the power subcircuit
    * Updates the specification
    * Improves the structure of the document
    * Adds SRAM high speed calculations
    * Adds structure of simulation sections
2025-10-22 ✅ Validate the SRAM symbol (#25)
    [clock.kicad_sch, ddr2.kicad_sch, emmc.kicad_sch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]
2025-10-22 ✅ Validate the SDRAM symbol (#26)
    [sdram.kicad_sch]
2025-10-22 ✅ Validate the Power symbols (#30)
    [power.kicad_sch]
2025-10-22 ✅ Validate the DDR2 symbols (#31)
    [ddr2.kicad_sch]
2025-10-22 ✅ Validate the schematic symbols (#33)
    [fpga-bank0.kicad_sch, fpga-bank1.kicad_sch, fpga-bank2.kicad_sch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]
2025-10-22 🔄 Replace the eMMC IC (#34)
    [clock.kicad_sch, ddr2.kicad_sch, ecap5-bsom.kicad_sch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]
2025-10-22 ✨ Add FPGA jtag circuit (#36)
    [ecap5-bsom.kicad_sch, fpga-bank0.kicad_sch, fpga-bank1.kicad_sch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]
2025-10-22 ✨ Add net classes to the schematic (#38)
    [ddr2.kicad_sch, emmc.kicad_sch, io-connector-1.kicad_sch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]
2025-10-22 ✅ Check each IC's supply voltage in the schematic (#39)
    [clock.kicad_sch, ddr2.kicad_sch, emmc.kicad_sch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]
2025-10-22 ✨ Replace some LVDS diff pairs with 3v3 single-ended signals (#56)
    * ✨ Replace some LVDS diff pairs with 3v3 single-ended signals
    * Finishes replacing LVDS diff pairs with 3v3 single ended
    [ddr2.kicad_sch, ecap5-bsom.kicad_sch, emmc.kicad_sch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]
2025-10-22 Adds L6981 footprint (#57)
    [ddr2.kicad_sch, emmc.kicad_sch, io-connector-1.kicad_sch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]
2025-10-22 Added the reference of passive components from the DC-DC converters (#62)
    [ddr2.kicad_sch, emmc.kicad_sch, io-connector-1.kicad_sch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]
2025-10-22 Added footprint for 744770127 (#63)
    [ddr2.kicad_sch, emmc.kicad_sch, io-connector-1.kicad_sch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]
2025-10-22 Adds footprint for etq-p5m220yfc (#64)
    [ddr2.kicad_sch, emmc.kicad_sch, io-connector-1.kicad_sch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]
2025-10-22 Adds footprint for ETQ-P3M2R2KVP (#65)
    [ddr2.kicad_sch, emmc.kicad_sch, io-connector-1.kicad_sch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]
2025-10-22 Add footprint for st1s41phr (#66)
    [ddr2.kicad_sch, emmc.kicad_sch, io-connector-1.kicad_sch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]
2025-10-22 Adds footprint for lm3880 (#67)
    [ddr2.kicad_sch, emmc.kicad_sch, io-connector-1.kicad_sch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]
2025-10-22 Add footprint for w25q128jvp (#68)
    [ddr2.kicad_sch, emmc.kicad_sch, flash.kicad_sch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]
2025-10-22 Add footprint for oscillator (#70)
    [clock.kicad_sch, ddr2.kicad_sch, emmc.kicad_sch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]
2025-10-22 Add footprint for sram (#71)
    [ddr2.kicad_sch, emmc.kicad_sch, io-connector-1.kicad_sch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]
2025-10-22 Add footprint for sdram (#72)
    [ddr2.kicad_sch, emmc.kicad_sch, io-connector-1.kicad_sch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]
2025-10-22 Add footprint for ddr2 (#73)
    [ddr2.kicad_sch, emmc.kicad_sch, io-connector-1.kicad_sch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]
2025-10-22 Add footprint for the emmc (#74)
    [ddr2.kicad_sch, emmc.kicad_sch, io-connector-1.kicad_sch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]
2025-10-22 Add footprint for ecp5 (#75)
    [ddr2.kicad_sch, emmc.kicad_sch, fpga-bank0.kicad_sch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]
2025-10-22 Add footprint for the io connector (#76)
    [ddr2.kicad_sch, emmc.kicad_sch, fpga-bank0.kicad_sch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]
2025-10-22 Add power good led (#77)
    [ddr2.kicad_sch, emmc.kicad_sch, io-connector-1.kicad_sch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]
2025-10-22 Add remaining component footprints (#79)
    [clock.kicad_sch, ddr2.kicad_sch, ecap5-bsom.kicad_pcb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]
2025-10-22 Use TI power ICs instead of ST (#81)
    * Update big inductors for smaller ones
    * Add TI power designer reports for buck converted
    * Add schematic for the 1V1 regulator
    * Replace the other buck converters
    * Add footprints for TI buck converters
    * Add remaining footprints
    * Update documentation following changes to power schematic
    [ddr2.kicad_sch, ecap5-bsom.kicad_pcb, emmc.kicad_sch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]
2025-10-22 Add notes on the schematic (#84)
    [ddr2.kicad_sch, emmc.kicad_sch, fpga-bank0.kicad_sch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]
2025-10-22 Define the board stackup and netclasses (#86)
    [ecap5-bsom.kicad_pcb]
2025-10-22 Route the board power supply (#89)
    * Replaces the inductors for smaller ones
    * Starts routing the power supply
    * Starts routing power
    * Start adding power planes
    * Adds decoupling capacitors
    * Adds routing of the power sequencing
    * Add routing for SRAM
    * Route the SRAM data pins
    * Finish routing the SRAM
    * Route the SDRAM
    * Move 1.8v converter to other side of the board
    * Start routing DDR2 data lanes
    * Use 0402 resistors instead of 0201 for emmc termination
    * Route signals from DDR2 to FPGA bank
    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
    [ddr2.kicad_sch, ecap5-bsom.kicad_pcb, ecap5-bsom.kicad_sch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]
2025-10-22 Finish routing the board
    * Start updating the power supply routing
    * Mirror the connector pinout
    * Start routing the connector
    * Add second SDRAM chip
    * Move decoupling capacitors to the top layer
    * Add power monitoring to the schematics
    * Start placing the power monitoring
    * Start routing the power monitoring
    * Add routing of the io connector gnd pins
    * Start routing the emmc
    * Fix schematic issues
    * Finish routing the emmc signals, no length matching
    * Fanout the ddr2
    * Route the data bus of ddr2
    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
    [ddr2.kicad_sch, ecap5-bsom.kicad_sch, emmc.kicad_sch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]
2025-10-22 Perform power integrity simulation (#93)
    * Add first power integrity simulation
    * Add power integrity simulation
    [plane-1v1.step, test.step]
2025-10-22 Add pull-up resistor on reset-in pin (#95)
    [fpga-bank8.kicad_sch]
2025-10-22 Add bom components
    [clock.kicad_sch, ddr2.kicad_sch, emmc.kicad_sch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]
2025-10-22 Update silkscreen
    [clock.kicad_sch, ddr2.kicad_sch, emmc.kicad_sch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]
2025-10-22 Fix the clearances
    [ddr2.kicad_sch, emmc.kicad_sch, io-connector-1.kicad_sch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]
2025-10-22 Final check before manufacturing
    [ddr2.kicad_sch, emmc.kicad_sch, fpga-bank7.kicad_sch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]
2025-10-22 Added production files
    [bom.csv, ddr2.kicad_sch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]

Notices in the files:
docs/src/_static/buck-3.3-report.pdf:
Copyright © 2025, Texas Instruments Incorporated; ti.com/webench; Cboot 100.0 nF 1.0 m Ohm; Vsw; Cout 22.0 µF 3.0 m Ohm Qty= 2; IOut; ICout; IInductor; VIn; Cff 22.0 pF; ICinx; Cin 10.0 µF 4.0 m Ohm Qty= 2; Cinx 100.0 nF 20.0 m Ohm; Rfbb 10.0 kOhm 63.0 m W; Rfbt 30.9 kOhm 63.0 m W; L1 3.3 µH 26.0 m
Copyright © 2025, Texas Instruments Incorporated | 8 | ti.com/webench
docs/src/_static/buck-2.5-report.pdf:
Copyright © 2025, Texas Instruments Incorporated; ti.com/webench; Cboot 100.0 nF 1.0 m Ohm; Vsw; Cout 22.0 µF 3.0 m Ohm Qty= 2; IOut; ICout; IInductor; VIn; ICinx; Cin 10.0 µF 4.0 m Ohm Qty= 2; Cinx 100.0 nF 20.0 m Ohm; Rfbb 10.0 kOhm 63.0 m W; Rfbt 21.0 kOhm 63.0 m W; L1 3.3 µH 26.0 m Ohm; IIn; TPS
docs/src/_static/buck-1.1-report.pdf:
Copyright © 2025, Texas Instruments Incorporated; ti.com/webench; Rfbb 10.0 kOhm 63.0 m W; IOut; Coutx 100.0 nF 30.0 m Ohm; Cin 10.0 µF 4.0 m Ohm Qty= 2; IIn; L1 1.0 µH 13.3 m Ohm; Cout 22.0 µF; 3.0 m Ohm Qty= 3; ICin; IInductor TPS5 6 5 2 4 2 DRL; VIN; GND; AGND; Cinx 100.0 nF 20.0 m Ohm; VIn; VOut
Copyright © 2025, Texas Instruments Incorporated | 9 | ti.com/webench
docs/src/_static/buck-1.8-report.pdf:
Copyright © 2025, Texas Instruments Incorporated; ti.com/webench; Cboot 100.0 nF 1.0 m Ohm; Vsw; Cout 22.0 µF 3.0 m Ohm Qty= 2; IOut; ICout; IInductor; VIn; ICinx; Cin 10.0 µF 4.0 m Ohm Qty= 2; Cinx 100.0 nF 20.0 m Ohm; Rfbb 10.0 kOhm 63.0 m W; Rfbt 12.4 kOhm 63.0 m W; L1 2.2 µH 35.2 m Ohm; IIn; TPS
